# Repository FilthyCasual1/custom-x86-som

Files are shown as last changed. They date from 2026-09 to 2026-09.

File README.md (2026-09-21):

# Custom x86 SOM — placement handoff

Open `hardware/x86-som-preliminary.kicad_pro` in KiCad 10. The matching schematic has 18 sheets; the matching PCB contains 96 staged components and zero routed tracks. Project-local symbol and footprint libraries are included. Move components in the PCB editor to start exploring placement; no board outline has been chosen.

**This is an incomplete preliminary design, not fabrication-ready.** See `hardware/LIBRARY-STATUS.md` for the current verification matrix. The CPU socket and Q370 still use padless placement envelopes. Other packages include source-checked geometry and explicitly marked provisional choices. Electrical and assembly validation remains incomplete.

The full library is `hardware/SOM_Full.kicad_sym`; use `hardware/parts-catalog.json` for part numbers. CPU socket: Foxconn PE115127-4041-01H. DDR4 sockets: TE2309407-1. The full pin inventories have1151 CPU contacts,874 PCH balls and456 BMC balls.

## Files

- `hardware/x86-som-preliminary.kicad_sch`: source-based schematic draft.
- `hardware/x86-som-preliminary.kicad_pcb`: component staging board with nets assigned to available pads.
- `hardware/SOM.kicad_sym`, `hardware/SOM.pretty/`: portable project libraries.
- `hardware/footprint-status.json`: footprint provenance and provisional status.
- `hardware/placement-validation.json`: component count and schematic nodes without pads.
- `hardware/open-items.md`: next engineering checks.
- `output/pdf/x86-som-preliminary.pdf`: schematic preview.
- `docs/reference/`, `docs/manifest.json`: downloaded documents and source inventory.
- `research/conversation-source.json`: recovered original specification conversation.

KiCad successfully exported the schematic and reloaded the 96-component PCB. ERC reports 102 errors and 349 warnings; see `hardware/erc.rpt`. These remain unresolved, and no routing, signal-integrity, power-integrity, boot or fabrication validation has been claimed.

The source specification is ChatGPT conversation “Compact SOM Motherboard Design”, ID `6ab03890-806c-83ea-97a4-768561390f3c`. Prior assistant claims are research leads. The earlier claimed downloadable engineering packs were not recovered. Actual donor schematics and manufacturer documents have been downloaded separately.

Generation scripts are development tools. **Do not rerun them after manual KiCad edits:** they overwrite schematic/PCB files and regenerate symbol UUIDs.

## Public repository contents

This public snapshot contains the KiCad files, libraries, generation scripts, engineering notes and previews from local commit `4b89cf6`. The original conversation archive and downloaded third-party reference documents/text extracts remain local; paths to those files describe the local research workspace. `docs/manifest.json` records the source inventory. Some generators require those local source files and will not run from this public checkout alone.

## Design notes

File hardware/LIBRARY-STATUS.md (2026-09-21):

# Library handoff

`SOM_Full.kicad_sym` contains 17 entries. `FH82Q370` has all 874 ball numbers from Intel Table11-1; `AST2500A2_GP` has all 456 populated balls from the ASPEED top-view maps, excluding 28 #N/A sites. `CoffeeLake_LGA1151` contains 1151 donor-extracted contacts. Complete pin inventories are separate from the partial circuit symbols so existing draft connections are preserved. All full inventory pins are passive: electrical types and multiplexed functions still need independent review. This is not a complete, validated motherboard library.

All selected symbols expose Manufacturer, MPN, Footprint and Status fields in the full library; schematic instances also have those fields. `parts-catalog.json` is the machine-readable catalog. TBD values are deliberate, not orderable parts.

| Item | Manufacturer part | Status |
|---|---|---|
| CPU socket | Foxconn PE115127-4041-01H | Manufacturer drawing downloaded. Solder-ball numbering and land geometry unresolved; padless placement reservation retained. CPU itself is separate. |
| DDR4 sockets | TE 2309407-1 | 4mm, standard orientation. Checked drawing5 sheet2; signal pads corrected to0.30x1.75mm. |
| EPS header | Molex39-28-1083 | Candidate for5566-08A footprint. Exact EPS keying and pad mapping unresolved; not purchase-approved. |
| Q370 | Intel FH82Q370 |874-pin inventory;23x24mm body confirmed. Pitch and recommended lands unresolved; padless. |
| BMC | ASPEED AST2500A2-GP |456pads,19x19mm,0.8pitch and depopulation checked against drawing/maps.0.35mm NSMD copper diameter is an engineering proposal, not a verified manufacturer recommendation. |
| VR controller | ISL95866HRZ-T | Renesas L52.6x6A pattern:0.4pitch,0.20x0.55 peripheral pads,4.7mm EP. Package-to-device association donor-derived. Complete controller datasheet fetch was denied403. |
| Host PHY | WGI219LM family | Corrected EP from4.4 to3mm;0.4pitch. Exact stepping unresolved. Peripheral pad extension and thermal vias require assembly review. |
| DDR termination | TPS51200DRCR | KiCad DRC10+EP pattern; exact TI package selected. |
|25MHz crystal | ABM8-25.000MHZ-D2Y-T | Correct4-pin mapping; case pins2/4 grounded; pad geometry corrected to manufacturer1.30x1.05 at±1.15/±0.875mm. Load-capacitance/startup validation pending. |
| RTC crystal | ABS07-32.768KHZ-7-T | Candidate7pF crystal. Generic3215 footprint remains unverified against recommended lands. |
| PHY inductor | LPS4018-472MRC | Exact4.7uH candidate. Stock footprint differs from manufacturer's shaped recommended lands; unresolved. Current/ripple not approved. |
| Input fuse |0451015.MRL | Candidate15A package only; stock1.96x3.15mm pads at±2.455 match published recommended dimensions. Protection coordination not approved. |
| Flash, resistors, capacitors | TBD | Package templates only; exact electrical selection unresolved. |

The PCB contains96components, of which U1/U2 remain padless. There are1639 netlist nodes without pads, predominantly these two placeholders. Do not mistake the incomplete ratsnest for a complete design. ERC remains451messages:64open pins,38undriven supply inputs,349isolated labels. These represent unfinished circuitry and were not suppressed to produce a false clean report.

Do not rerun the generation scripts after manual KiCad edits: they overwrite files and regenerate UUIDs. The full inventory variants are available for future replacement of partial circuit symbols, not automatically substituted into this schematic.

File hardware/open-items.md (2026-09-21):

# Current status supersedes earlier checklist

See LIBRARY-STATUS.md. Only U1/U2 remain padless; missing pad nodes now1639. Earlier sizes and eight-placeholder list below are historical.

# Resume checklist

Work paused at user's requested symbol/footprint placement handoff.

1. Replace padless envelopes U1/U2/U3/U20/Y1/Y2/F1/L600 with exact orderable-part land patterns. CPU 78 x 78 mm envelope is an arbitrary socket/mechanism reservation, not its measured outline. Q370/AST2500/VR outlines are provisional too. Confirm all stock footprint pad mappings, EPS keying, SO-DIMM socket orientation and connector height. I219 exposed-pad size is a candidate, not independently validated.
2. Current symbols are incomplete for PCH and AST2500. CPU pin extraction has 1151 unique pins, but independent datasheet checking remains required. Donor H310 circuitry does not validate a Q370 design. AST2500 memory interface exists but its memory IC, complete supply pins and LAN circuit are absent.
3. Complete CPU VR power stages, inductors, compensation, rail sizing/sequencing, PCH/BMC regulators and full decoupling. The ISL95866 controller transcription is only a donor reference, not a complete VRM. TPS51200 REFIN uses a provisional 0.6 V divider.
4. Check DDR4 2DPC topology, SO-DIMM pin mapping, termination, SPD, VPP/VTT and length/impedance rules. No reference-board DQ swaps were assumed valid for this layout.
5. Complete host PHY support and BMC PHY/magnetics, RTC/clock/strap/reset circuits, carrier connector selection and allocation, firmware/BIOS/BMC bring-up plan. No carrier connector footprint is yet chosen or placed.
6. Resolve 451 ERC messages (102 errors / 349 warnings), including open pins, incomplete supplies and isolated nets. Board has 1780 netlist nodes without corresponding pads, predominantly major-chip placeholders. Do not interpret its incomplete ratsnest as complete connectivity.
7. Establish final cooler/socket datum and outline, stackup, routing rules and mounting. Do not manufacture the staging layout.

## Preserved mechanical inputs

User owns Dell 9020 USFF cooler; supplied part references 0VXD9P / 04X9H2 / 0FGW90 and https://www.ebay.com/itm/163252658404. User measured approximately 6 mm underside clearance at the far edge and 7+ mm under the fan. These are user-provided clearances, not verified full cooler geometry. Cooler geometry is only needed for board outline at this stage. No cooler keepout or board outline is frozen.

## Electrical allocation under consideration

Coffee Lake-S LGA1151 + Q370, four DDR4 SO-DIMMs, CPU 2 x PCIe x8, AST2500, one host I219-LM GbE plus dedicated BMC Ethernet, EPS12V. Proposed PCH lane allocation reserves lane 5 for integrated GbE, lane 6 for AST2500, lanes 13–24 as three x4 uplinks, and lanes 1–4/7–12 as ten x1 links. This remains subject to exact Q370 port grouping, HSIO and firmware checks.

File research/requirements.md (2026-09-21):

# Recovered requirements

Source turn IDs refer to conversation-source.json. Later user decisions supersede earlier alternatives.

| Requirement | Evidence / status |
|---|---|
| Custom-built compact SOM, not a purchased module | User e489a088-b775-43a3-9347-7546c615806f |
| LGA1151 socket | User ffe6aea0-88a6-45e8-87d1-2a5e93b71265 |
| Four SO-DIMM sockets; two direct x8 CPU PCIe links; extensive x1 expansion | Initial user f3331d3b-775d-45c0-b359-b6b09c3ab676 |
| Coffee Lake-S / Q370 platform | Working architecture from prior discussion; exact CPU SKU/support list remains open |
| ASPEED BMC | User 21da610f-d5e8-4298-b970-36f947f638f8; AST2500 was the proposed implementation |
| Native x1 links plus carrier switches | Accepted by user e3cca0a1-25ed-42ec-9e25-9c0096a0db84; numerical allocation needs correction |
| Single integrated host GbE | User 34e104bf-5dbd-4353-96c1-0a2119030bda supersedes dual-host-GbE request |
| Dedicated BMC management Ethernet | Working architecture; dual management Ethernet was an assistant misunderstanding, not a retained requirement |
| Dell OptiPlex 9020 USFF blower cooler; board length follows cooler | User 5504d366-3890-4078-8114-ad4ef38d9f11 and 4c18245f-9b8e-4f8e-9550-e49036dbaa59 |
| Cooler removal for RAM service acceptable | User 1222fbf4-fb03-4248-ab1a-631aa3162e16 |
| Prioritize VRM beneath cooler/blower; fit RAM where possible | User 8b330e31-4ca0-419f-be5c-208c1b9776f9 |
| Separate generic VRM heatsink acceptable | User f838818f-8efe-44ce-a342-ce01d8f6e62e |
| 8-pin EPS12V power connector | User 7c87185e-401d-4113-9492-df72ce8600a6 |
| Actual usable datasheets/downloads; mirrors acceptable; avoid payment-credit download sites | Multiple user turns on source page 2 and 7e52c8d3-5bae-4577-8053-9b922b5472e5 |
| KiCad | Current user instruction |

## Decisions still open

Exact CPU SKU and sustained/transient limits; cooler part number/dimensions; connector family and pinout; SATA/USB/display counts; standby source; full power sequencing; firmware implementation and provisioning; CPU VR controller/stages; BMC RAM and flash sizing; TPM and Super I/O need; production quantity/cost target; fabricator and stackup.

The previous assistant's suggestions of 95 W electrical capability, 65 W cooling, 12–16 layers, heavy copper, specific heatsink dimensions and 12 V-derived standby are not verified requirements or validated limits.

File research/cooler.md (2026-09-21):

# Dell 9020 USFF cooler

User owns the physical cooler and explicitly authorized internet research and estimates for initial design. Proceed with provisional mechanical planning; dimensions are not a reason to stop the research.

User-specified cooler reference: **0VXD9P / 04X9H2 / 0FGW90**, supplied with [eBay listing 163252658404](https://www.ebay.com/itm/163252658404). The listing was opened and confirms those three identifiers in its title for the Dell 9020 USFF CPU fan/heatsink. Use this assembly as the mechanical research target. The listing does not establish that all three numbers denote interchangeable complete assemblies or provide a dimensioned mechanical drawing. The separate OEM assembly listing below identifies 4X9H2 as the assembly number; exact fan/subassembly mapping remains unverified.

Sources found:

- [Dell official USFF removal procedure](https://www.dell.com/support/manuals/en-us/optiplex-9020-desktop/opt9020usffom-v2/removing-the-heat-sink-assembly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): primary reference for assembly context and retention. Inspect illustrations before deriving geometry.
- [Parts-People OEM assembly listing](https://www.parts-people.com/index.php?action=item&id=25822): seller identifies the USFF assembly as 4X9H2; corroboration lead, not a dimensioned drawing.

No dimensions have been verified or estimated yet. Next: inspect official illustrations and available orthogonal photographs; build a parameterized envelope and label each inferred dimension with its source and uncertainty. Keep socket datum, fastener positions, blower intake clearance, SO-DIMM service envelope and VRM heatsink envelope separately adjustable. Do not release fabrication holes or claim cooling performance from photo estimates.

Latest user measurements: ~6 mm clearance at far edge, 7+ mm directly under fan. Cooler geometry is deferred to board outline; no outline fixed at placement handoff.

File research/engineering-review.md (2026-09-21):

# Initial engineering review

## Confirmed source access

Opened these complete PDFs through the web tool during intake; not yet downloaded locally:

- [Intel CPU 337344-009](https://cdrdv2-public.intel.com/337344/337344_8th-gen-core-family-datasheet-vol-1_Rev009.pdf): 155 PDF pages.
- [Intel PCH 337347-009](https://cdrdv2-public.intel.com/337347/337347_CNL_PCH_EDS_H_009.pdf): 301 PDF pages. Printed pages differ from PDF indices.

## HSIO conflict requiring correction

Intel 337347 Table 1-4 and Section 3 show shared PCIe/GbE/SATA resources. Integrated GbE consumes a PCIe-capable HSIO lane. Thus the inherited allocation of AST2500 x1 + eleven native x1 + three x4 uplinks (24 PCIe lanes) cannot also retain integrated GbE. The 15-root-port limit with GbE is a separate constraint; meeting it does not fix lane multiplexing.

An arithmetic starting point is ten native x1 + AST2500 x1 + three x4 uplinks = 23 PCIe lanes, reserving one HSIO lane for GbE. This is not a validated lane map. SATA reservations may reduce expansion further. Verify numbered lanes, controller groupings, straps and clock ownership before accepting it. If 24 carrier x1 endpoints remain desired, switches would need fourteen downstream x1 ports total with ten native links.

## Candidate parts inherited from discussion

These are leads only: no stock, price, exact order code or electrical compatibility has been verified in this intake.

| Block | Candidate | Required next evidence |
|---|---|---|
| CPU socket | TE 2287402-1 / Foxconn 3H993921-4M41-02H | Exact package, ball map, ILM, mounting and availability |
| SO-DIMM sockets | TE 2309407-5 | Stack height, insertion/retention envelope, drawing and footprint |
| BMC | AST2500 | Full pinout, power/reset sequence, DDR topology and firmware support |
| Host PHY | I219-LM | Correct generation/order code for Q370, supply and shared HSIO mapping |
| Management PHY | DP83867IS | AST2500 RGMII timing, supply compatibility, exact package |
| CPU VR | ISL95856 / ISL95866C / ISL69138 | Full documentation, SVID support, phases, stage interface, transient budget |
| Power stage | ISL99227 family | Controller compatibility; do not combine merely because both were suggested |
| Memory power | TPS51116 / TPS51200 | Host and BMC current budgets, VPP and sequencing |
| Carrier switches | PEX8713 | Full databook, straps, downstream widths, procurement and firmware |
| Clock buffers | 9DB836 / 9DBL0641 | Clock tree, loading, jitter budget, termination and enable control |
| Flash | W25Q256JV | Firmware capacity, bus voltage, boot addressing and recovery ownership |
| TPM | SLB9670 | Whether required; package and SPI electrical compatibility |

Earlier messages proposed PEX8714 for x1 fanout and later retracted it. Keep it excluded pending independent width-support verification. Earlier BMC RAM examples were also retracted over lifecycle concerns; no RAM part is frozen.

## Blocking inputs for real layout

- Exact cooler geometry and board/carrier datums are unavailable locally. Do not invent board dimensions or assume the cooler proves a particular power rating.
- CPU/PCH design guides, complete ball maps, memory routing limits and full selected VR documentation need acquisition and revision checks.
- Firmware feasibility must cover memory initialization, Intel CSME configuration, GPIO/HSIO straps, CPU support, flash programming and BMC recovery.
- Carrier pin budget must include grounds, clocks, reset/clock-request sidebands, management and power, not just differential data contacts.
- Full schematic connectivity and a supported fabrication stackup must precede production routing.

Next work: retrieve electrical documents, validate the numbered HSIO map, and compare exact parts and mechanical envelopes. User was asked for any existing downloaded document/design folder and cooler part number.

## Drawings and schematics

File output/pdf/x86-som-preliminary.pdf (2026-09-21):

1 | 2 | 3 | 4 | 5 | 6 | 7 | 8 | 9 | 10 | 11

AB

C

D

E

## FGH

AB

C

D

E

## FGH Date:

Size: A2 | Rev:
KiCad E.D.A. 10.0.6 | Id: 1/18

# Title:

## File: x86-som-preliminary.kicad_sch

## Sheet: /

CPU display and audio interface inventory

File: 07_cpu_display.kicad_sch

Q370 PCIe lane inventory / draft allocation

File: 09_pch_expansion.kicad_sch CPU remaining debug / reserved contacts

File: 08_cpu_reserved_7.kicad_sch

EPS12V input and unresolved regulator interfaces

File: 14_input_power.kicad_sch

AST2500 host links, boot flash and reset File: 13_bmc_host.kicad_sch Q370 power-domain interface inventory

# File: 12_pch_power.kicad_sch Q370 USB2 and PCIe clocks

File: 11_pch_usb_clocks.kicad_sch Q370 boot flash, LPC and reset interfaces

File: 10_pch_boot.kicad_sch

CPU VR controller / source-based starting circuit File: 15_vrm_controller.kicad_sch

CPU rails and power-pin inventory

File: 06_cpu_power.kicad_sch DDR4 supply interfaces, termination and socket power File: 05_memory_power.kicad_sch DDR4 channel B / two SO-DIMMs

# File: 04_ddr_b.kicad_sch DDR4 channel A / two SO-DIMMs

# File: 03_ddr_a.kicad_sch CPU PEG / two x8 carrier links

# File: 02_cpu_peg.kicad_sch CPU / Q370 DMI, clocks and sideband

File: 01_cpu_platform.kicad_sch | Host GbE PHY / I219 reference circuit File: 16_host_lan.kicad_sch AST2500 local DDR4 / pin-level interface

File: 17_bmc_ddr.kicad_sch

Known omissions: CPU VRM / sequencer / BMC DDR+power+LAN / host PHY / full PDN / connector pinout / remaining PCH GPIO.

# CUSTOM x86 SOM / preliminary schematic v0.1

SOURCE-BASED ELECTRICAL DRAFT - incomplete circuits are listed on each sheet Coffee Lake-S + Q370 + four DDR4 SO-DIMMs + AST2500

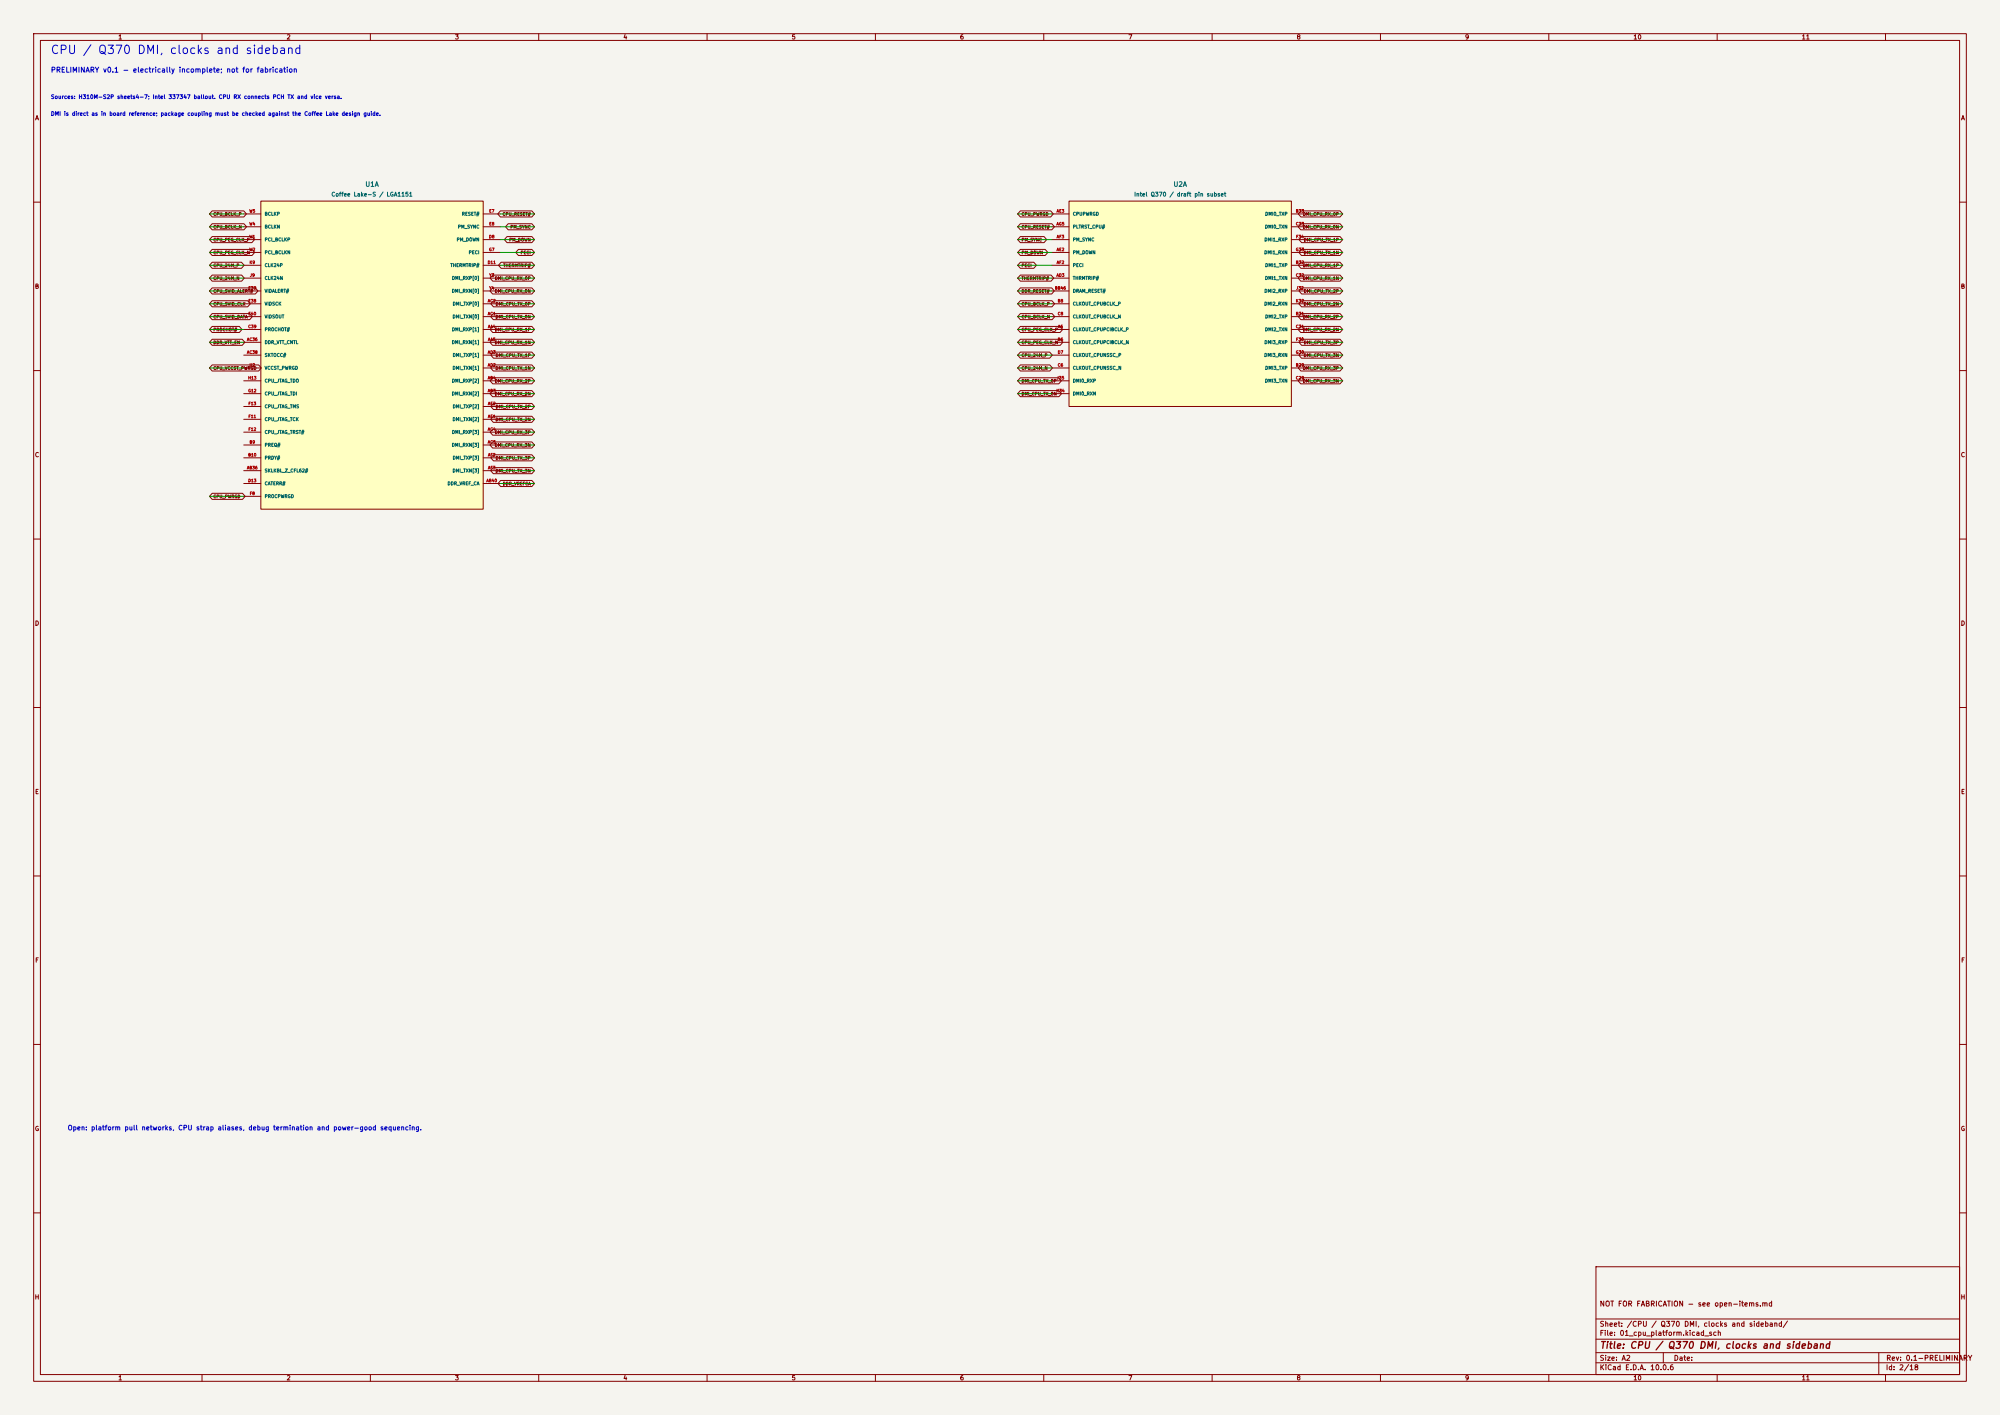
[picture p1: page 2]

PM_SYNC CPU / Q370 DMI, clocks and sideband

PRELIMINARY v0.1 - electrically incomplete; not for fabrication

Sources: H310M-S2P sheets4-7; Intel 337347 ballout. CPU RX connects PCH TX and vice versa. DMI is direct as in board reference; package coupling must be checked against the Coffee Lake design guide.

Open: platform pull networks, CPU strap aliases, debug termination and power-good sequencing.

NOT FOR FABRICATION - see open-items.md

Sheet: /CPU / Q370 DMI, clocks and sideband/
File: 01_cpu_platform.kicad_sch
Title: CPU / Q370 DMI, clocks and sideband

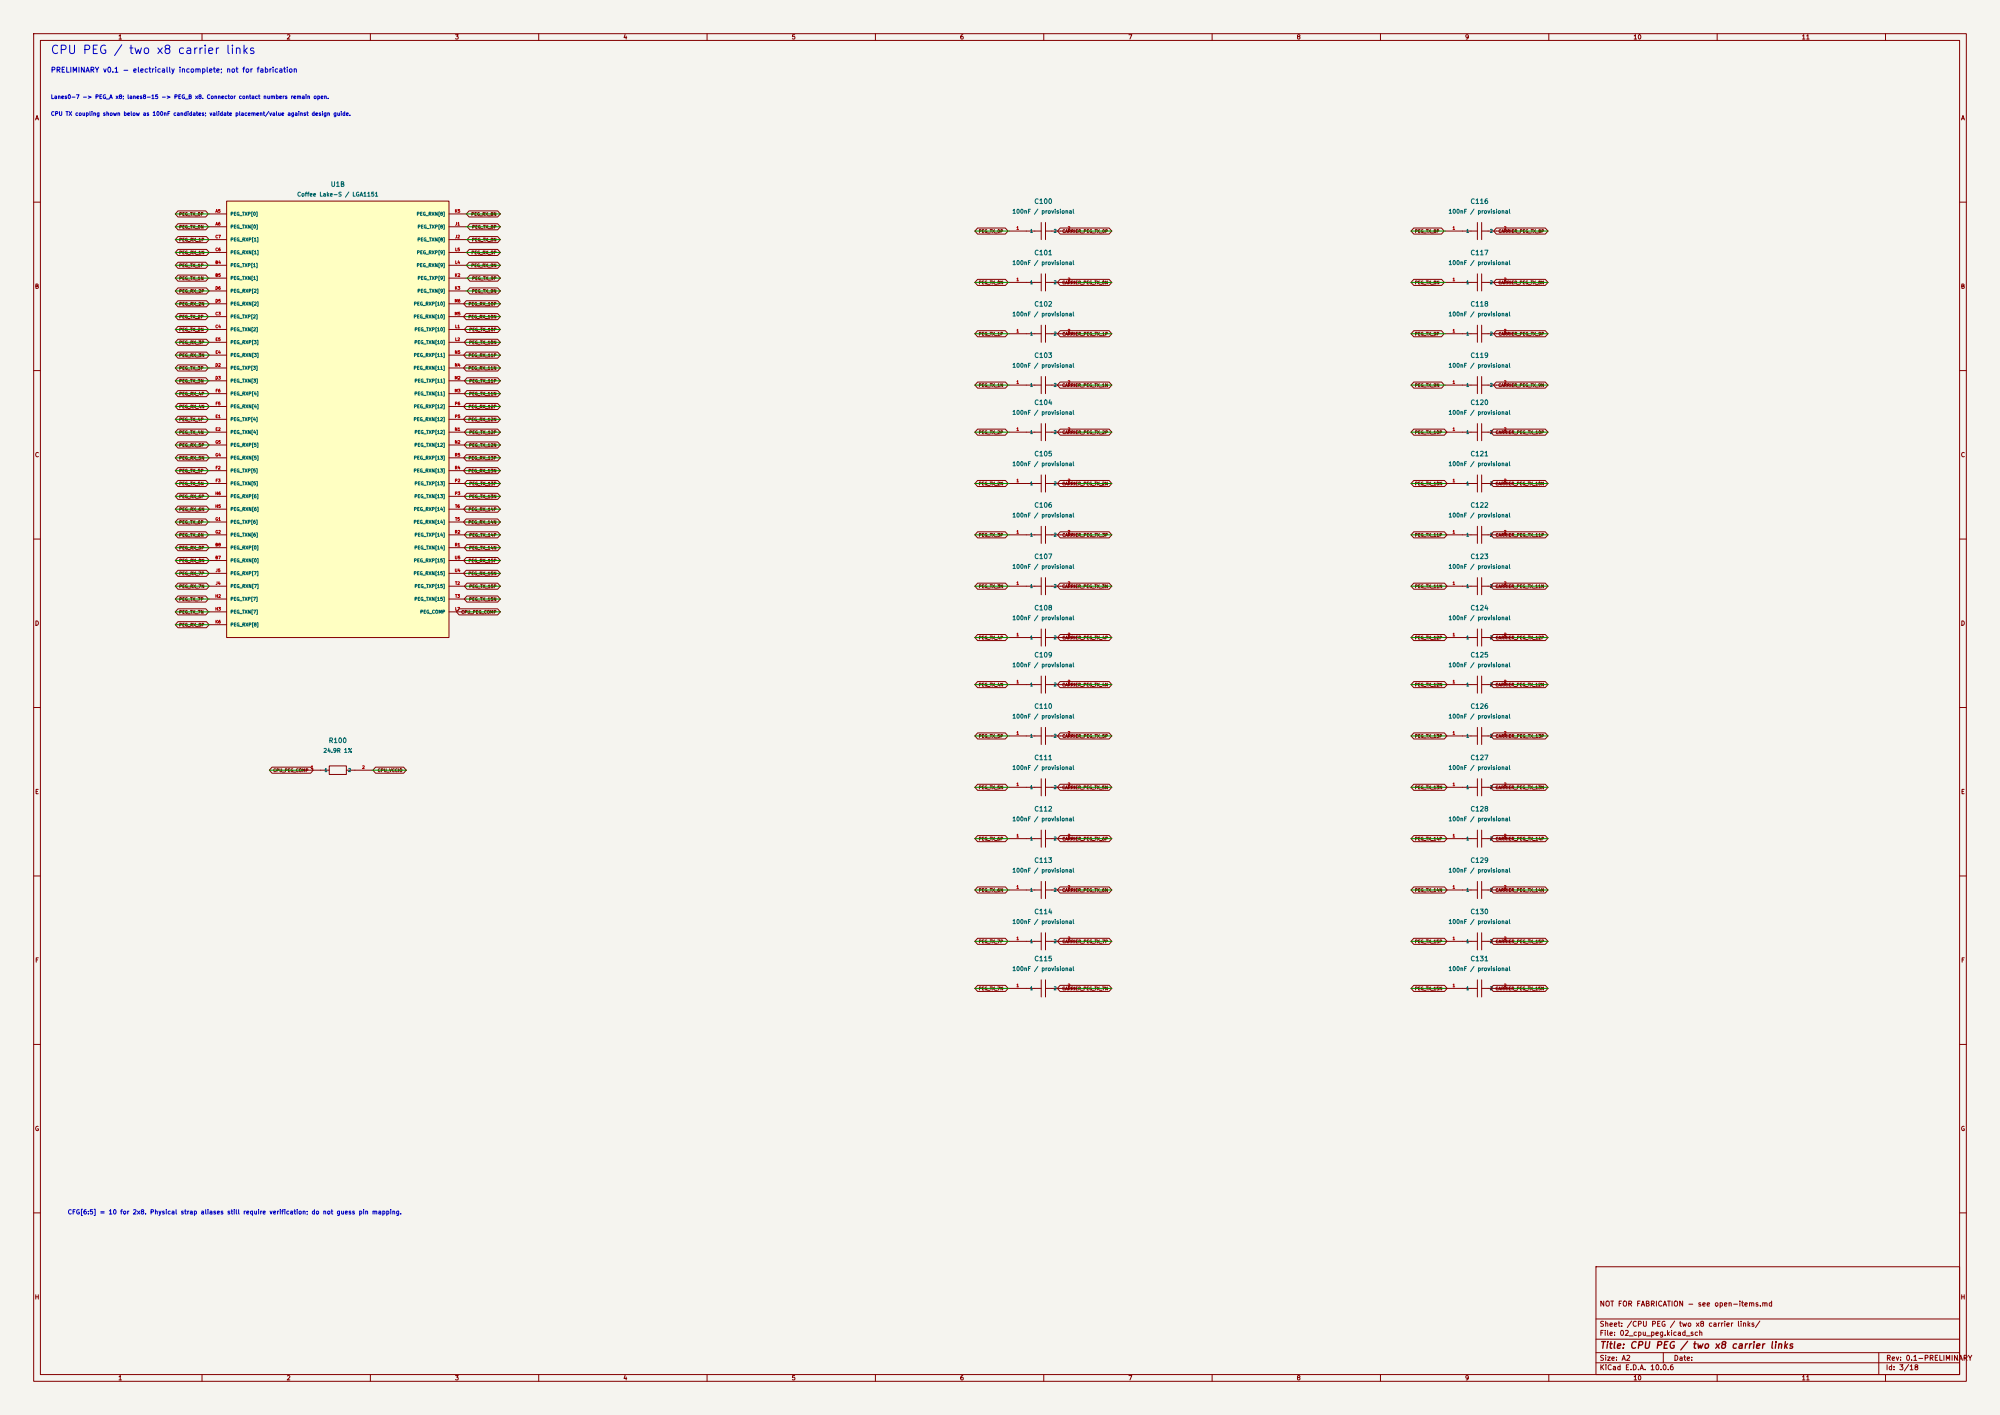
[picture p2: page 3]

CPU PEG / two x8 carrier links

Lanes0-7 -> PEG_A x8; lanes8-15 -> PEG_B x8. Connector contact numbers remain open. PRELIMINARY v0.1 - electrically incomplete; not for fabrication

CPU TX coupling shown below as 100nF candidates; validate placement/value against design guide.

CFG[6:5] = 10 for 2x8. Physical strap aliases still require verification; do not guess pin mapping.

Sheet: /CPU PEG / two x8 carrier links/
File: 02_cpu_peg.kicad_sch
Title: CPU PEG / two x8 carrier links

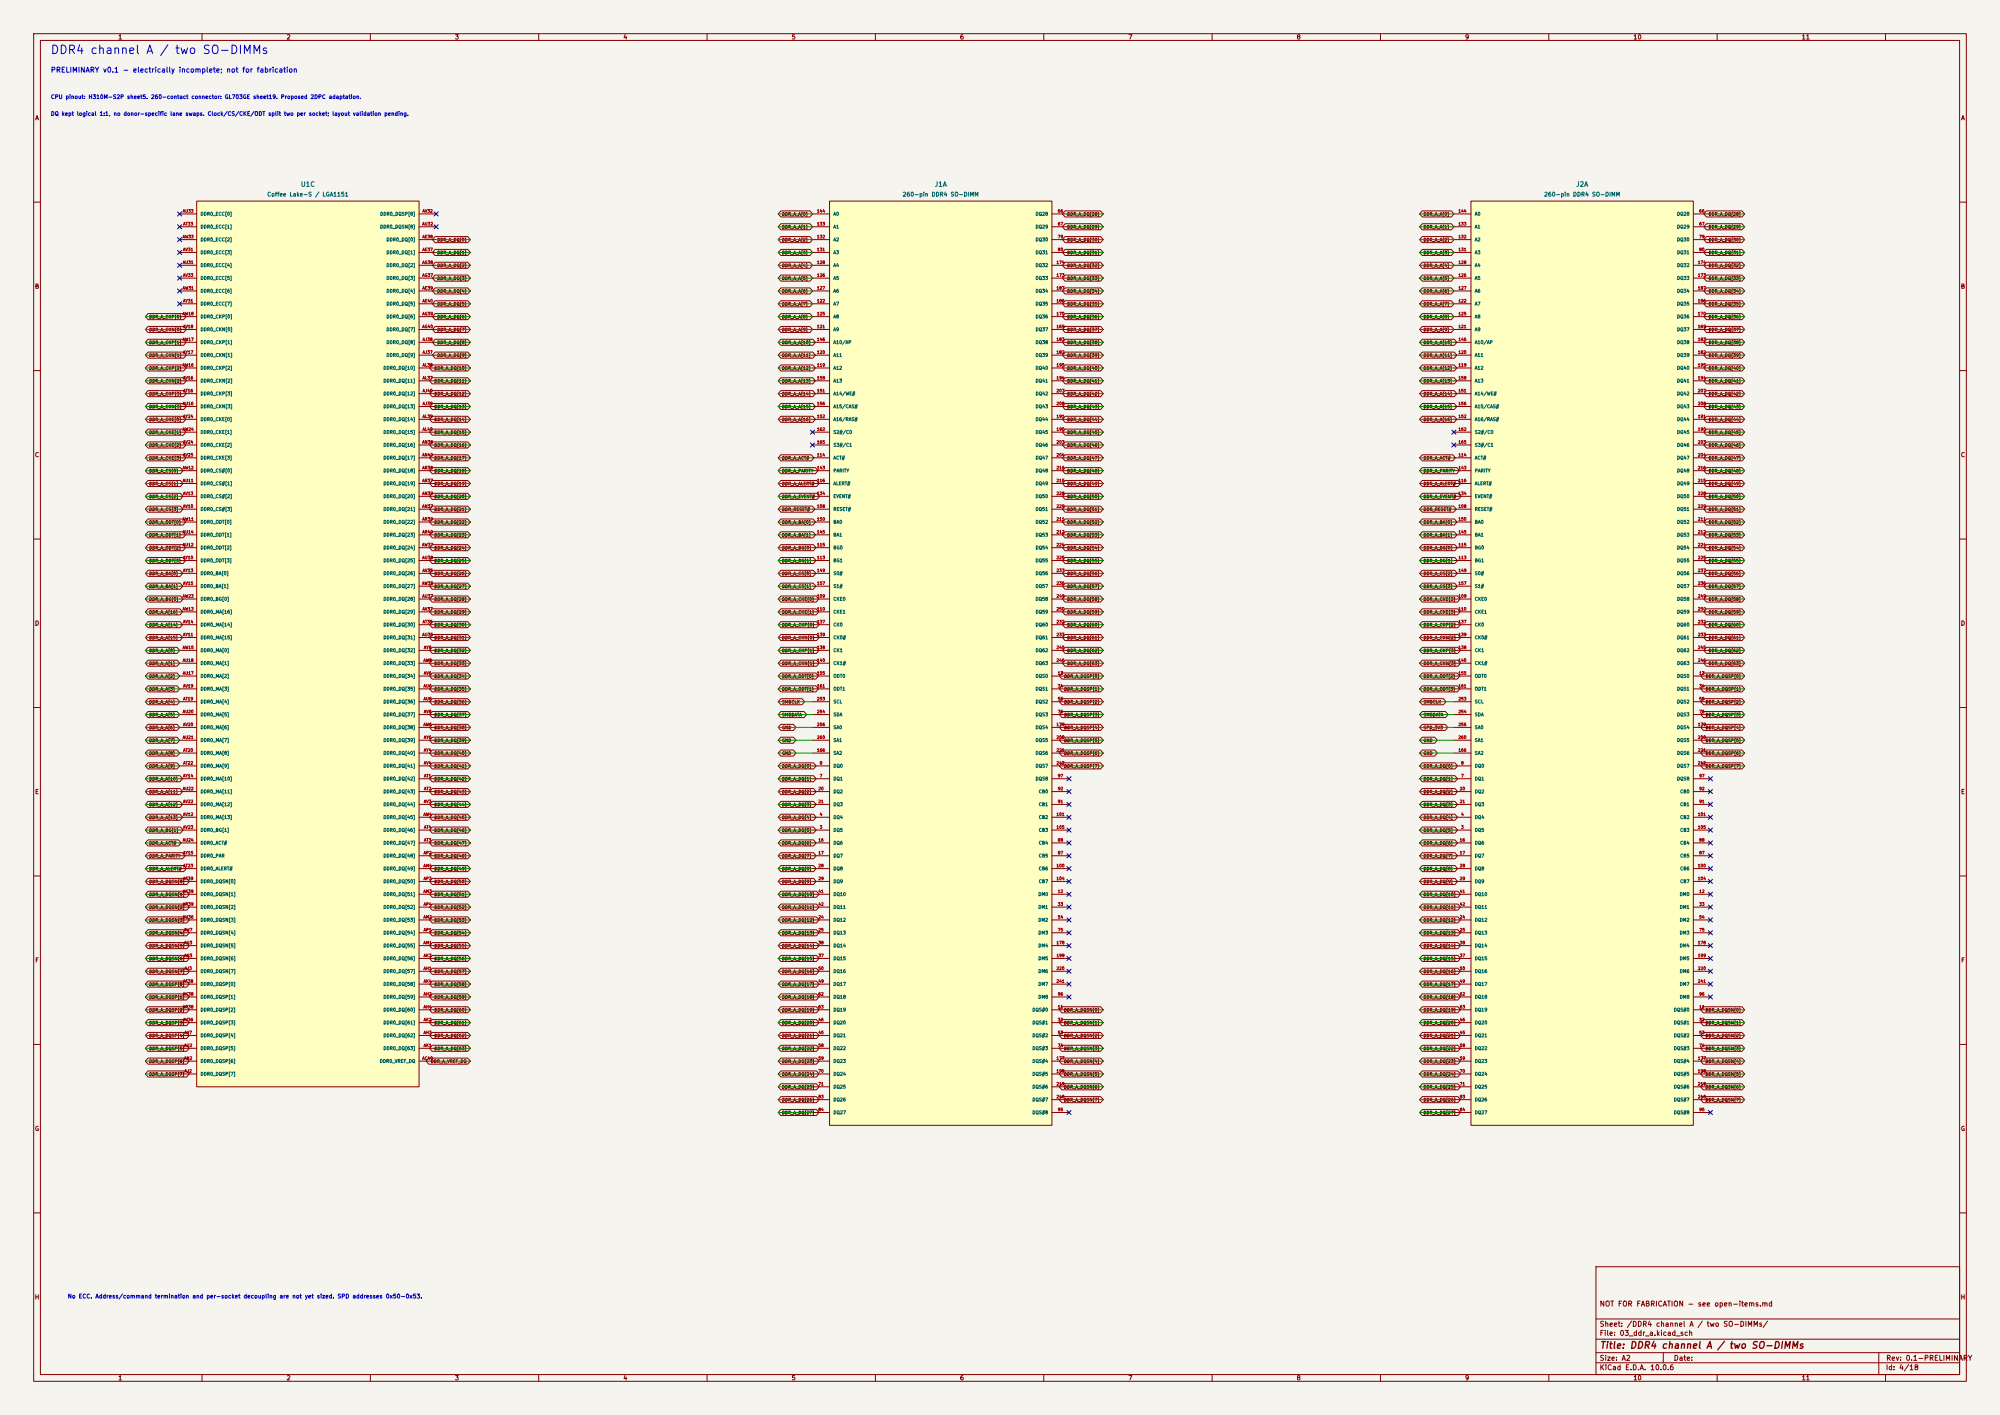
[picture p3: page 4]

DDR4 channel A / two SO-DIMMs

DQ kept logical 1:1, no donor-specific lane swaps. Clock/CS/CKE/ODT split two per socket; layout validation pending. CPU pinout: H310M-S2P sheet5. 260-contact connector: GL703GE sheet19. Proposed 2DPC adaptation.

No ECC. Address/command termination and per-socket decoupling are not yet sized. SPD addresses 0x50-0x53.

Sheet: /DDR4 channel A / two SO-DIMMs/
File: 03_ddr_a.kicad_sch
Title: DDR4 channel A / two SO-DIMMs

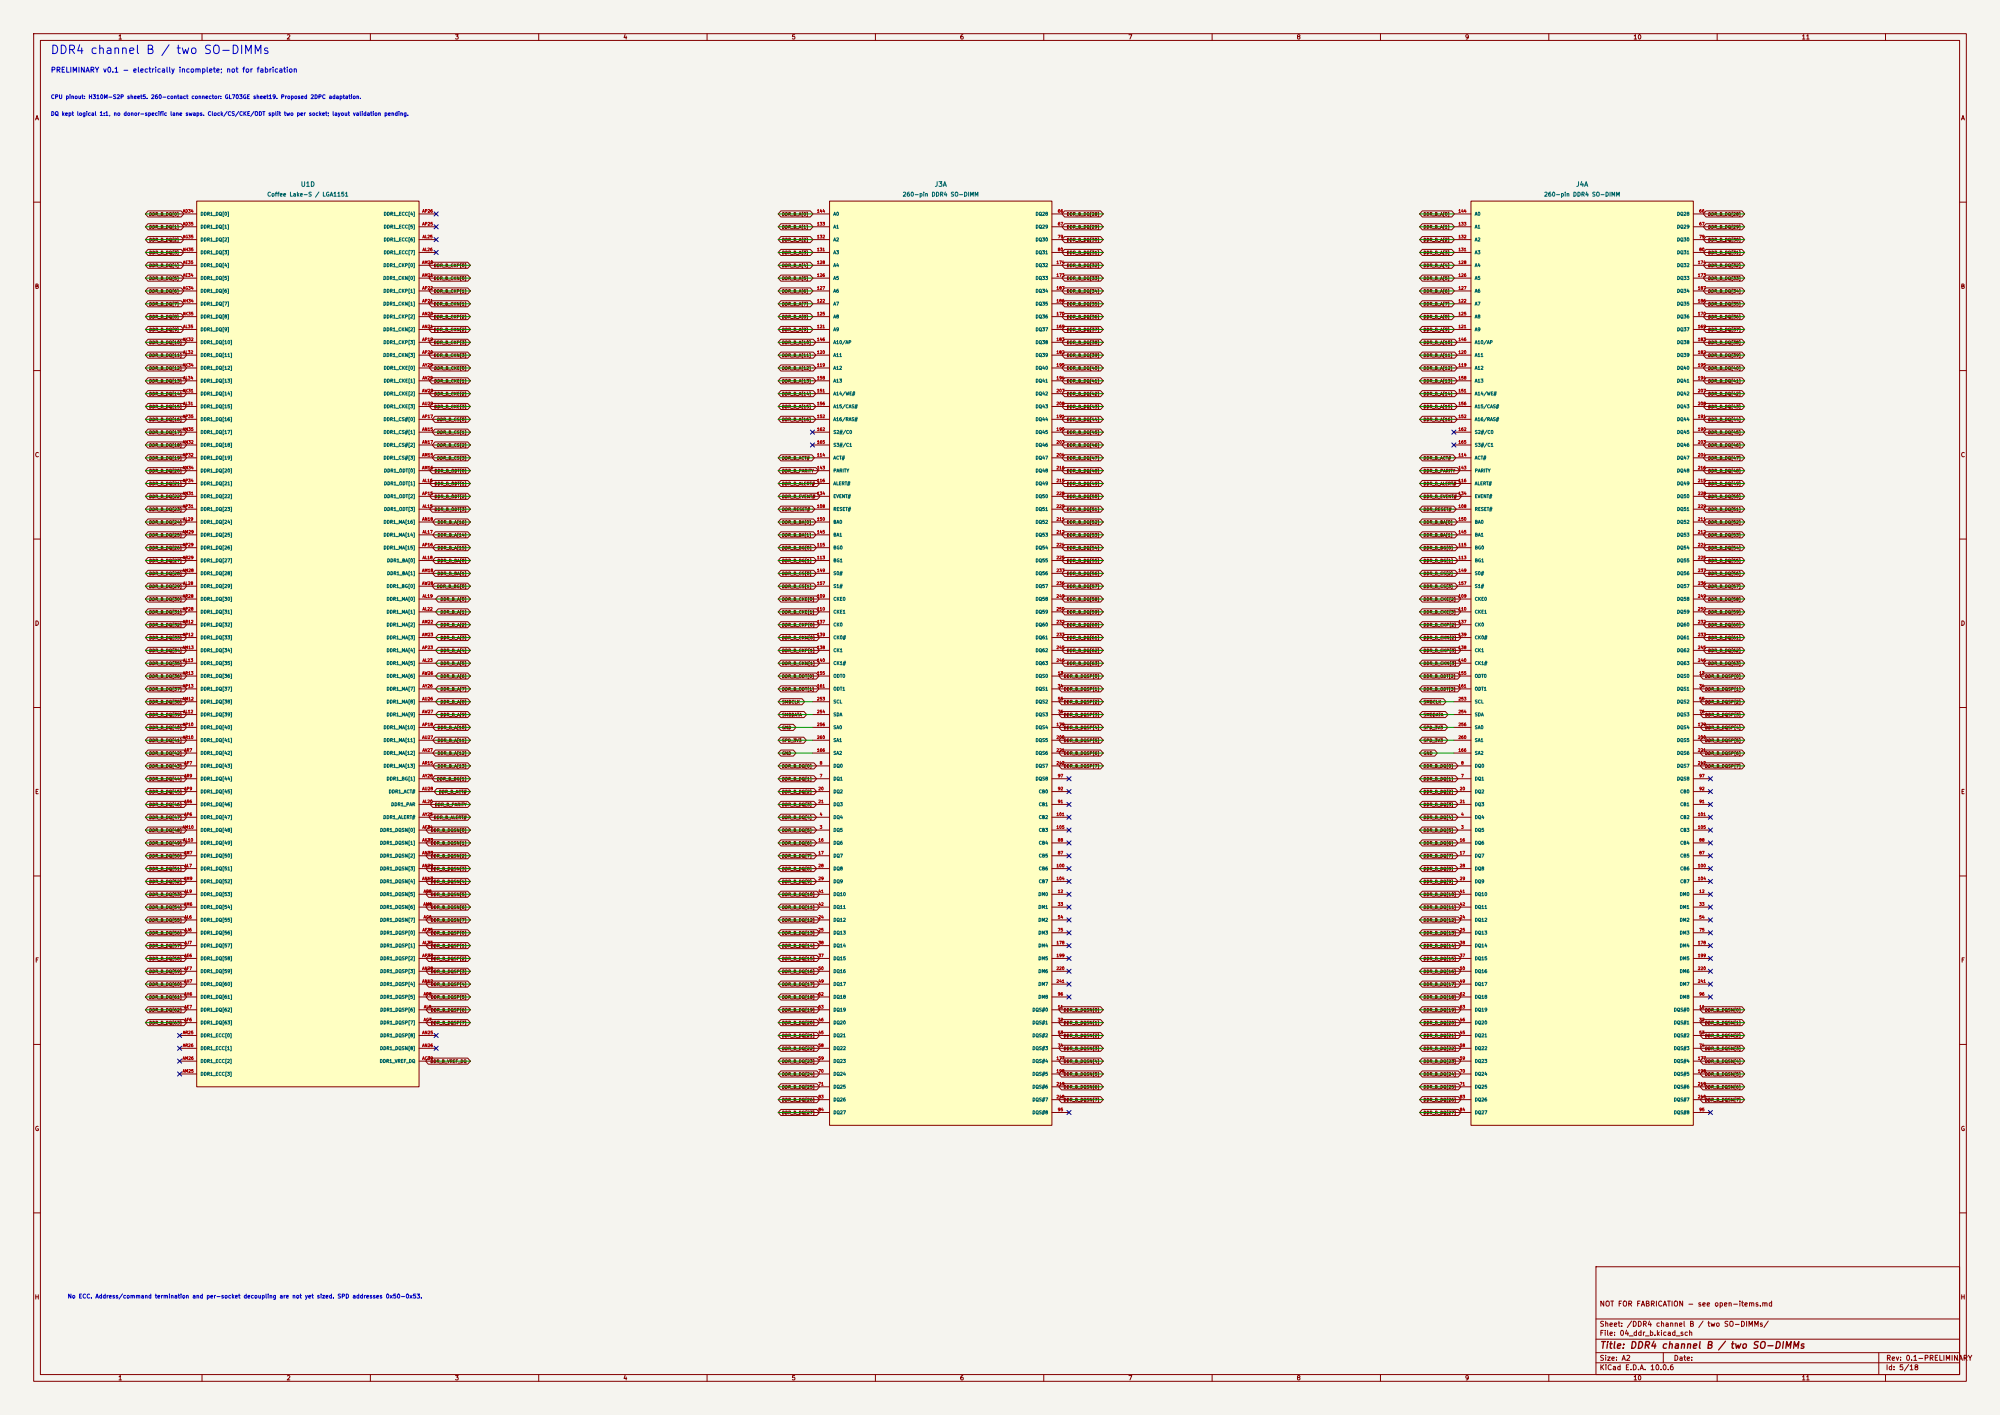
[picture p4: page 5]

DDR_B_DQ[8] DDR4 channel B / two SO-DIMMs

CPU pinout: H310M-S2P sheet5. 260-contact connector: GL703GE sheet19. Proposed 2DPC adaptation. DQ kept logical 1:1, no donor-specific lane swaps. Clock/CS/CKE/ODT split two per socket; layout validation pending.

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

Sheet: /DDR4 channel B / two SO-DIMMs/
File: 04_ddr_b.kicad_sch
Title: DDR4 channel B / two SO-DIMMs

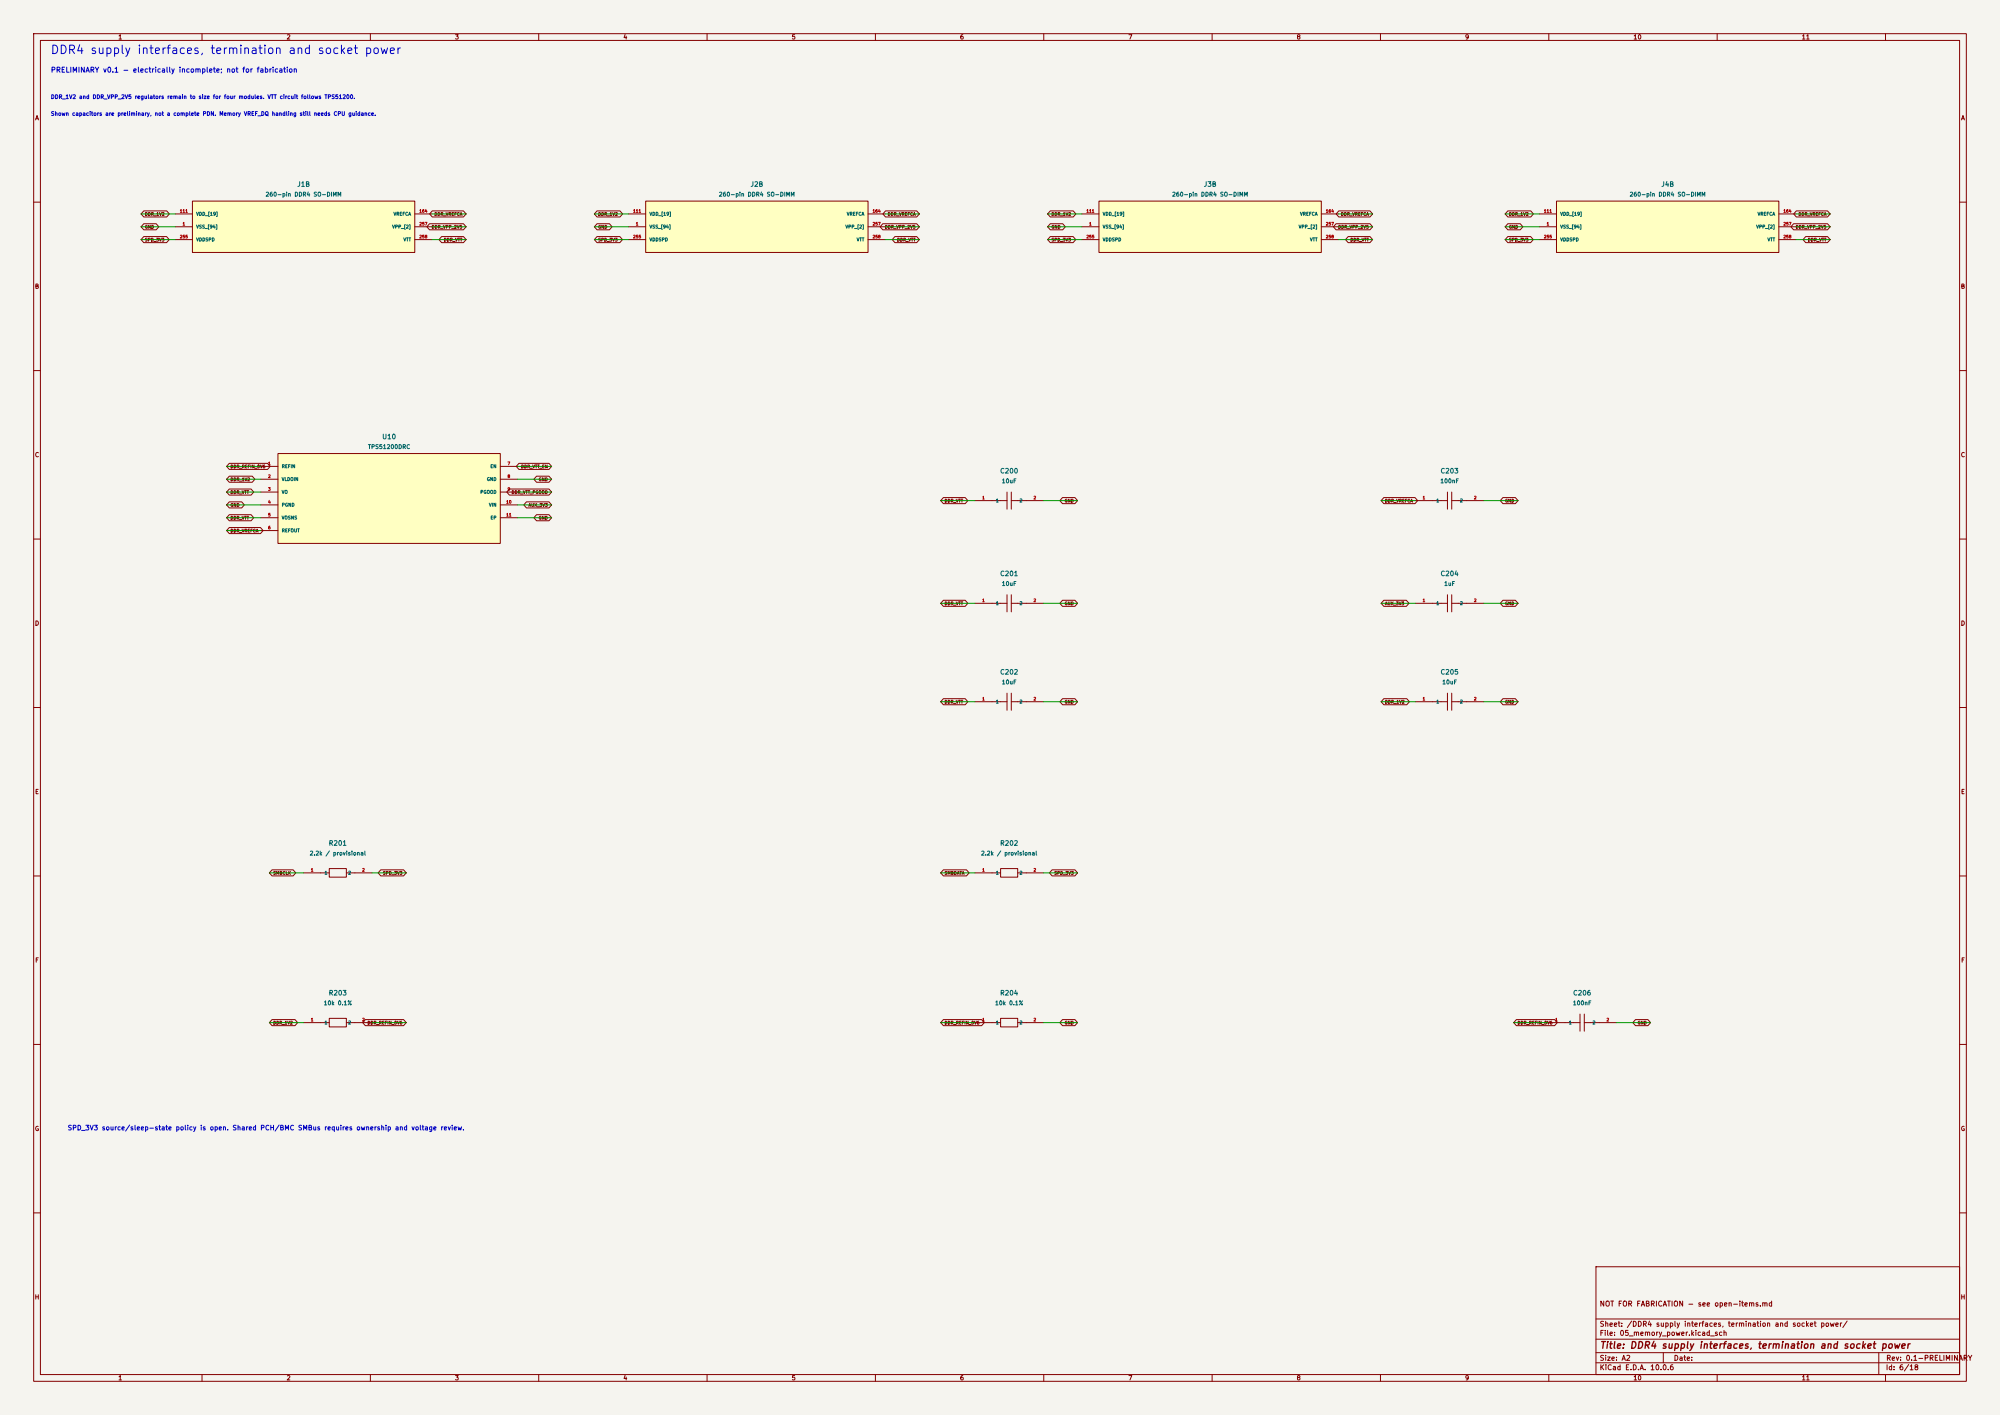
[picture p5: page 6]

Shown capacitors are preliminary, not a complete PDN. Memory VREF_DQ handling still needs CPU guidance. DDR_1V2 and DDR_VPP_2V5 regulators remain to size for four modules. VTT circuit follows TPS51200. PRELIMINARY v0.1 - electrically incomplete; not for fabrication

SPD_3V3 source/sleep-state policy is open. Shared PCH/BMC SMBus requires ownership and voltage review.

Sheet: /DDR4 supply interfaces, termination and socket power/
File: 05_memory_power.kicad_sch
Title: DDR4 supply interfaces, termination and socket power

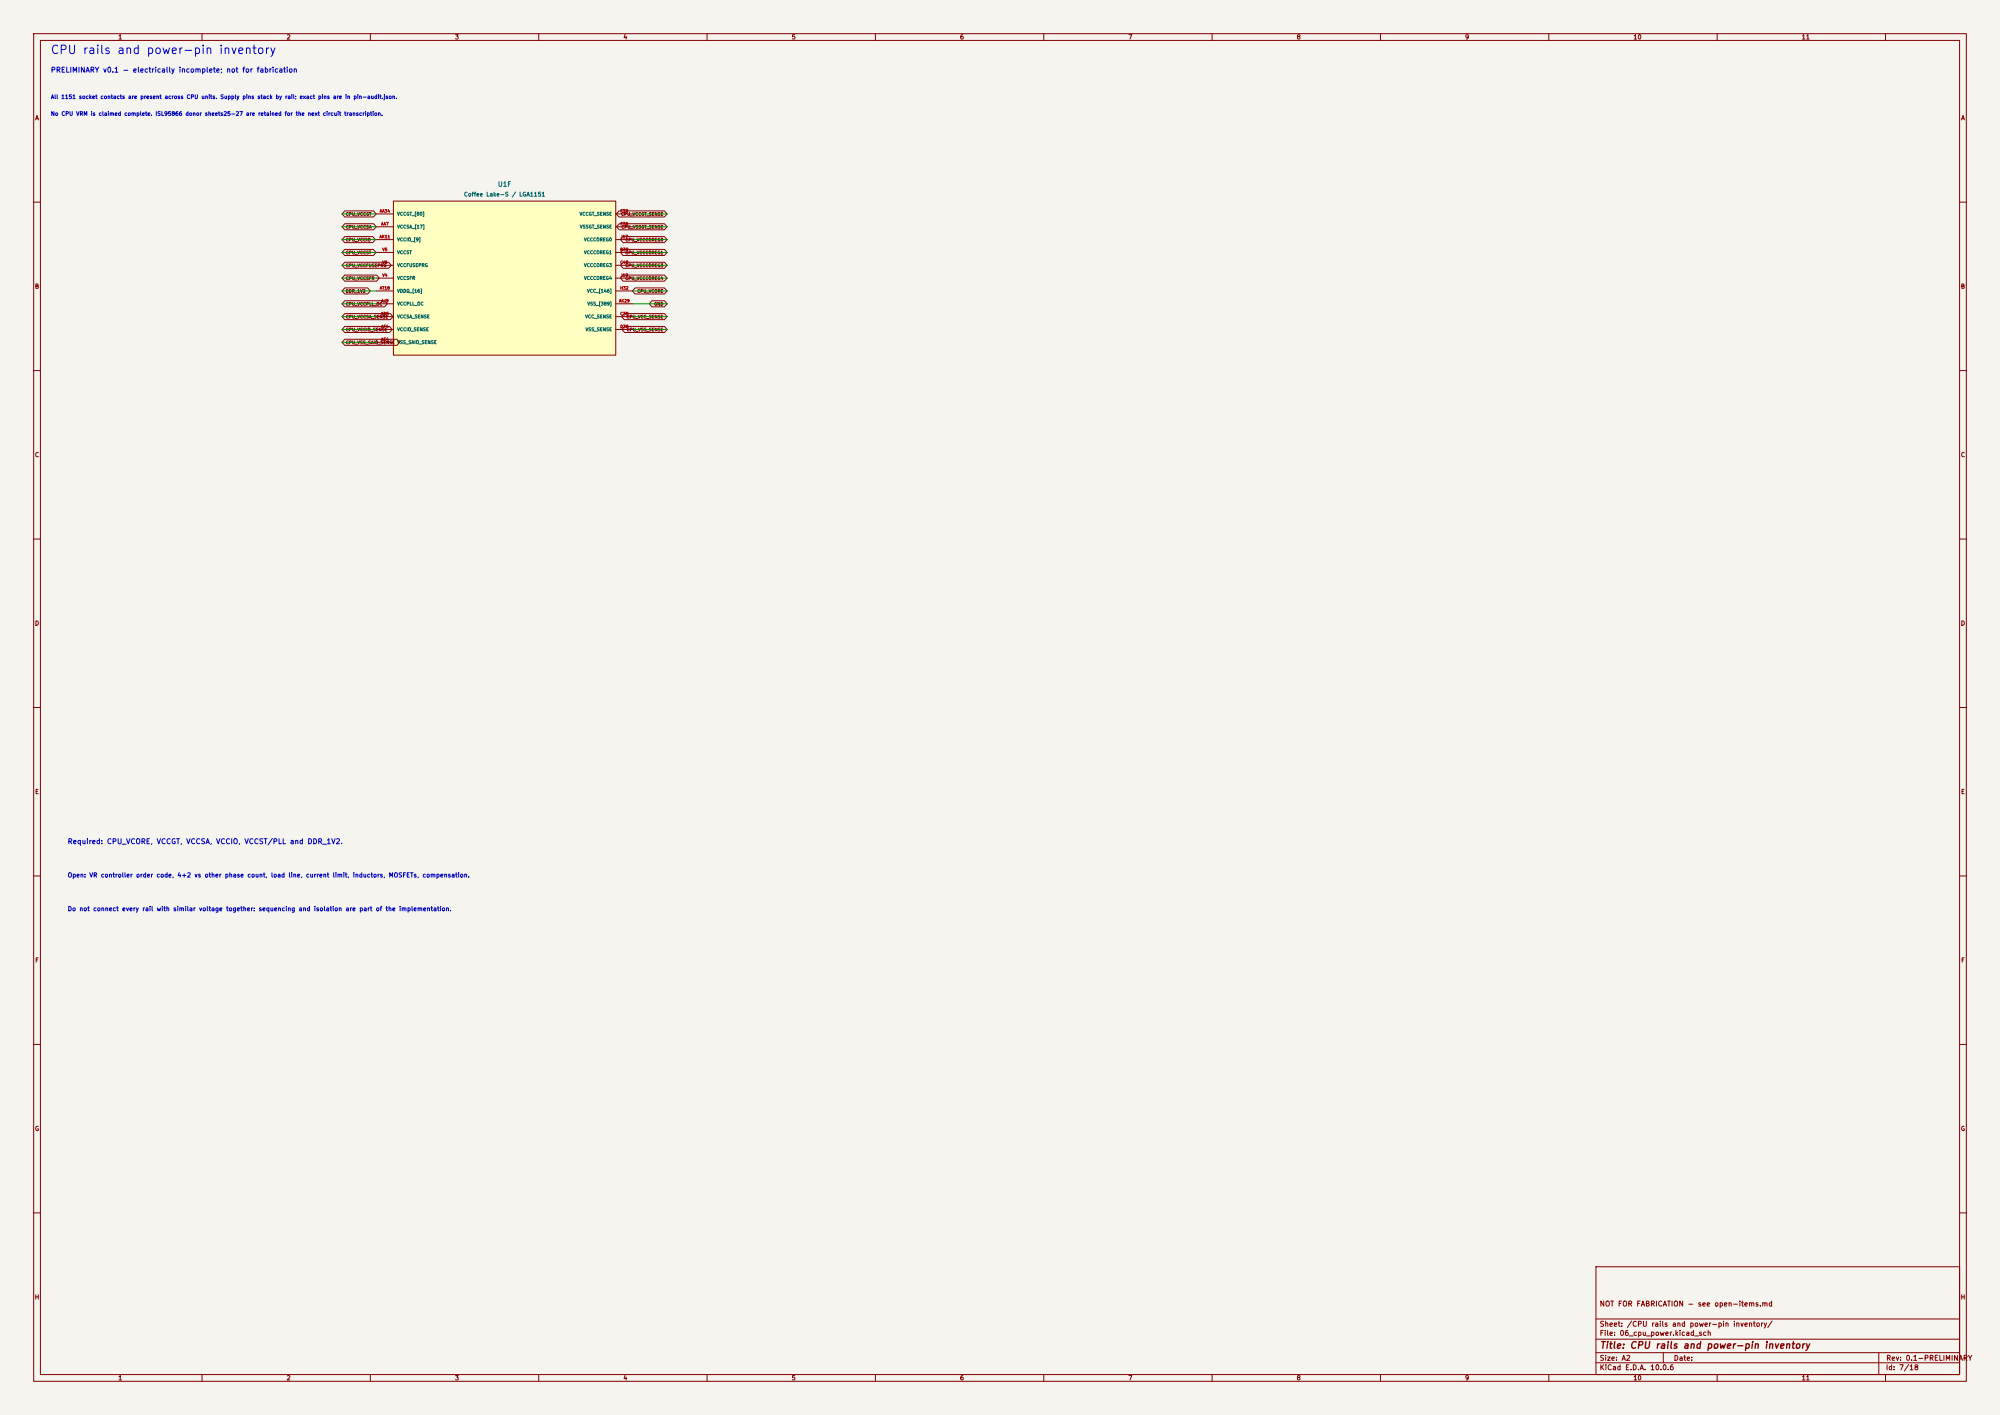
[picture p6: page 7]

CPU rails and power-pin inventory
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

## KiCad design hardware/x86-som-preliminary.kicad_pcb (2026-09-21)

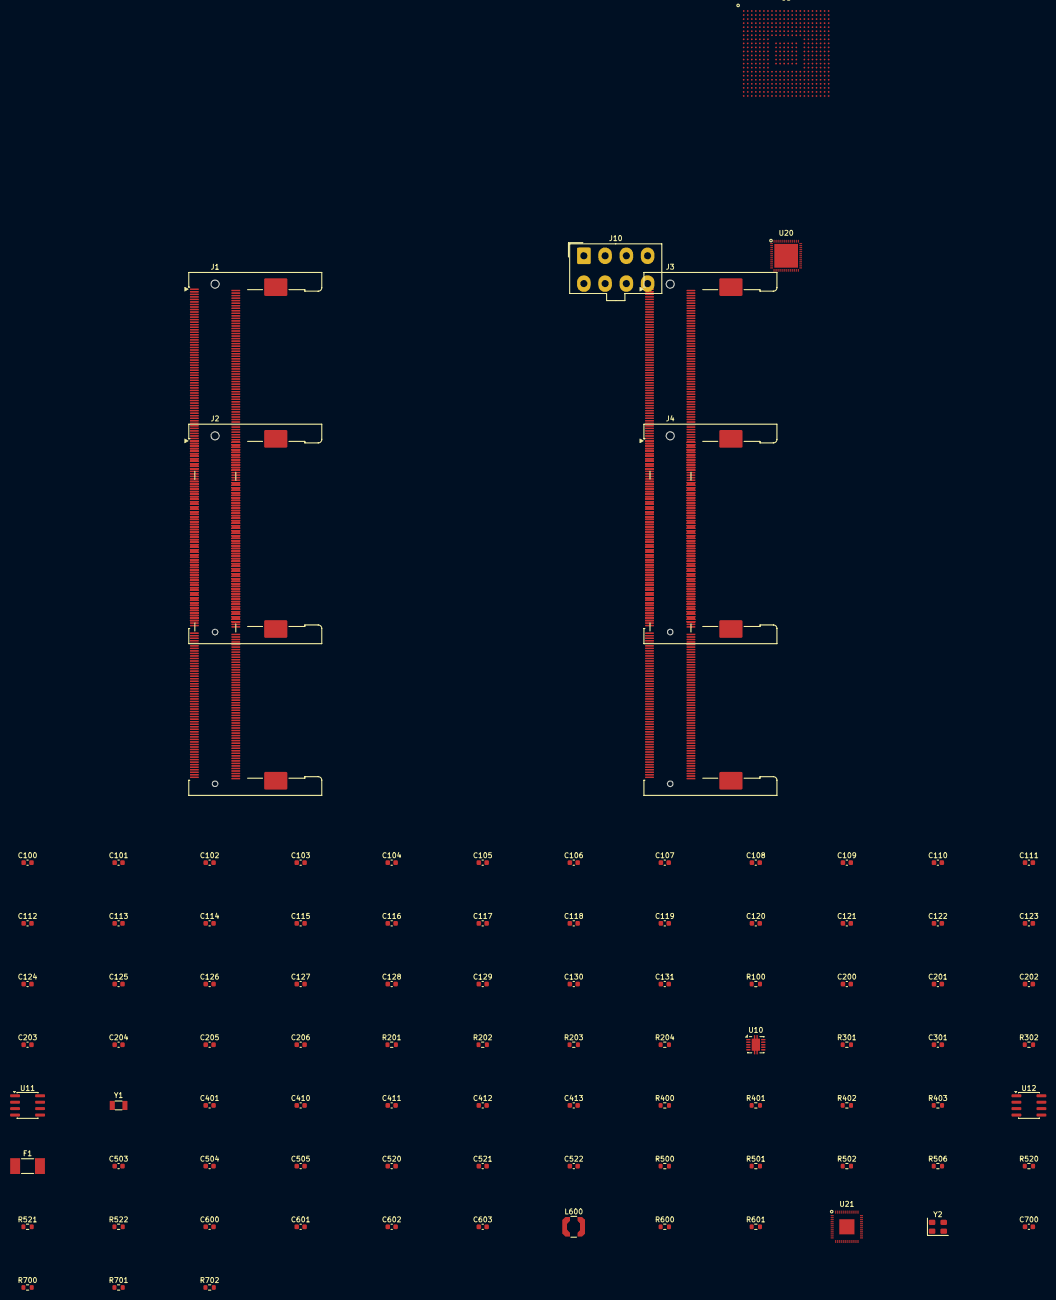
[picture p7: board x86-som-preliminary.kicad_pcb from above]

Board: 2 copper layers, 96 parts (0 on the bottom side), 267 nets, no tracks yet.

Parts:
C100, C101, C102, C103, C104, C105, C106, C107, C108, C109, C110, C111, C112, C113, C114, C115, C116, C117, C118, C119, C120, C121, C122, C123, C124, C125, C126, C127, C128, C129, C130, C131, C410, C411, C412, C413, C600, C601, C602, C603: 100nF / provisional; C_0603_1608Metric
C200, C201, C202, C205: 10uF; C_0603_1608Metric
C203, C206, C301, C401, C700: 100nF; C_0603_1608Metric
C204, C503, C504, C505: 1uF; C_0603_1608Metric
C520, C521, C522: 220nF / donor; C_0603_1608Metric
F1: Fuse / rating TBD; Fuse_Littelfuse-NANO2-451_453
J1, J2, J3, J4: 260-pin DDR4 SO-DIMM; SODIMM-260_DDR4_H4.0-5.2_OrientationStd_Socket
J10: EPS12V 8-pin; Molex_Mini-Fit_Jr_5566-08A_2x04_P4.20mm_Vertical
L600: 4.7uH / Intel; L_Coilcraft_LPS4018
R100, R301: 24.9R 1%; R_0603_1608Metric
R201, R202: 2.2k / provisional; R_0603_1608Metric
R203, R204: 10k 0.1%; R_0603_1608Metric
R302, R402, R403: 10k / provisional; R_0603_1608Metric
R400: 200R 1%; R_0603_1608Metric
R401: 10k; R_0603_1608Metric
R500, R501, R502: 2.2R; R_0603_1608Metric
R506: 2.87k 1% / donor; R_0603_1608Metric
R520, R521, R522: 2.2R / donor; R_0603_1608Metric
R600: 3.01k 1%; R_0603_1608Metric
R601: 1k; R_0603_1608Metric
R700: 240R 1%; R_0603_1608Metric
R701, R702: 10k 0.1% / provisional; R_0603_1608Metric
U1: Coffee Lake-S / LGA1151; CoffeeLake_LGA1151_PLACEMENT_ONLY
U2: Intel Q370 / draft pin subset; Q370_draft_PLACEMENT_ONLY
U3: AST2500 host/boot subset; ASPEED_AST2500A2_GP_BGA456_19x19_P0.8
U10: TPS51200DRC; VSON-10-1EP_3x3mm_P0.5mm_EP1.65x2.4mm
U11, U12: SPI NOR / capacity TBD; SOIC-8_3.9x4.9mm_P1.27mm
U20: ISL95866HRZ-T / donor reference; Renesas_L52_6x6A_QFN52_EP4.7
U21: I219-LM / revision TBD; Intel_I219_QFN48_EP3
Y1: 32.768kHz / CL TBD; Crystal_SMD_3215-2Pin_3.2x1.5mm
Y2: ABM8-25.000MHZ-D2Y-T; Crystal_SMD_3225-4Pin_3.2x2.5mm

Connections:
AUX_3V3: C204.1, U10.10
AUX_5V: R500.1, R501.1
BMC_3V3: C401.1, R402.2, R403.2, U12.8
BMC_ENTEST: R401.1, U3.K3
BMC_FLASH_HOLD#: R403.1, U12.7
BMC_FLASH_WP#: R402.1, U12.3
BMC_MIOZ: R700.1, U3.W11
BMC_MVREF: C700.1, R701.2, R702.1, U3.T9
BMC_PEREXT: R400.1, U3.K20
BMC_RX_N: C411.2, U3.M22
BMC_RX_P: C410.2, U3.M21
BMC_SPI_CLK: U3.AA18, U12.6
BMC_SPI_CS#: U3.AB19, U12.1
BMC_SPI_MISO: U3.T18, U12.2
BMC_SPI_MOSI: U3.U17, U12.5
BMC_TX_N: C413.1, U3.L22
BMC_TX_P: C412.1, U3.L21
CPU_VCCIO: R100.2, R301.2
DDR_1V2: C205.1, J1.111, J1.112, J1.117, J1.118, J1.123, J1.124, J1.129, J1.130, J1.135, J1.136, J1.141, J1.142, J1.147, J1.148, J1.153, J1.154, J1.159, J1.160, J1.163, J2.111, J2.112, J2.117, J2.118, J2.123, J2.124, J2.129, J2.130, J2.135, J2.136, J2.141, J2.142, J2.147, J2.148, J2.153, J2.154, J2.159, J2.160, J2.163, J3.111, J3.112, J3.117, J3.118, J3.123, J3.124, J3.129, J3.130, J3.135, J3.136, J3.141, J3.142, J3.147, J3.148, J3.153, J3.154, J3.159, J3.160, J3.163, J4.111, J4.112, J4.117, J4.118, J4.123, J4.124, J4.129, J4.130, J4.135, J4.136, J4.141, J4.142, J4.147, J4.148, J4.153, J4.154, J4.159, J4.160, J4.163, R203.1, U10.2
DDR_A_ACT#: J1.114, J2.114
DDR_A_ALERT#: J1.116, J2.116
DDR_A_A[0]: J1.144, J2.144
DDR_A_A[1]: J1.133, J2.133
DDR_A_A[2]: J1.132, J2.132
DDR_A_A[3]: J1.131, J2.131
DDR_A_A[4]: J1.128, J2.128
DDR_A_A[5]: J1.126, J2.126
DDR_A_A[6]: J1.127, J2.127
DDR_A_A[7]: J1.122, J2.122
DDR_A_A[8]: J1.125, J2.125
DDR_A_A[9]: J1.121, J2.121
DDR_A_A[10]: J1.146, J2.146
DDR_A_A[11]: J1.120, J2.120
DDR_A_A[12]: J1.119, J2.119
DDR_A_A[13]: J1.158, J2.158
DDR_A_A[14]: J1.151, J2.151
DDR_A_A[15]: J1.156, J2.156
DDR_A_A[16]: J1.152, J2.152
DDR_A_BA[0]: J1.150, J2.150
DDR_A_BA[1]: J1.145, J2.145
DDR_A_BG[0]: J1.115, J2.115
DDR_A_BG[1]: J1.113, J2.113
DDR_A_DQSN[0]: J1.11, J2.11
DDR_A_DQSN[1]: J1.32, J2.32
DDR_A_DQSN[2]: J1.53, J2.53
DDR_A_DQSN[3]: J1.74, J2.74
DDR_A_DQSN[4]: J1.177, J2.177
DDR_A_DQSN[5]: J1.198, J2.198
DDR_A_DQSN[6]: J1.219, J2.219
DDR_A_DQSN[7]: J1.240, J2.240
DDR_A_DQSP[0]: J1.13, J2.13
DDR_A_DQSP[1]: J1.34, J2.34
DDR_A_DQSP[2]: J1.55, J2.55
DDR_A_DQSP[3]: J1.76, J2.76
DDR_A_DQSP[4]: J1.179, J2.179
DDR_A_DQSP[5]: J1.200, J2.200
DDR_A_DQSP[6]: J1.221, J2.221
DDR_A_DQSP[7]: J1.242, J2.242
DDR_A_DQ[0]: J1.8, J2.8
DDR_A_DQ[1]: J1.7, J2.7
DDR_A_DQ[2]: J1.20, J2.20
DDR_A_DQ[3]: J1.21, J2.21
DDR_A_DQ[4]: J1.4, J2.4
DDR_A_DQ[5]: J1.3, J2.3
DDR_A_DQ[6]: J1.16, J2.16
DDR_A_DQ[7]: J1.17, J2.17
DDR_A_DQ[8]: J1.28, J2.28
DDR_A_DQ[9]: J1.29, J2.29
DDR_A_DQ[10]: J1.41, J2.41
DDR_A_DQ[11]: J1.42, J2.42
DDR_A_DQ[12]: J1.24, J2.24
DDR_A_DQ[13]: J1.25, J2.25
DDR_A_DQ[14]: J1.38, J2.38
DDR_A_DQ[15]: J1.37, J2.37
DDR_A_DQ[16]: J1.50, J2.50
DDR_A_DQ[17]: J1.49, J2.49
DDR_A_DQ[18]: J1.62, J2.62
DDR_A_DQ[19]: J1.63, J2.63
DDR_A_DQ[20]: J1.46, J2.46
DDR_A_DQ[21]: J1.45, J2.45
DDR_A_DQ[22]: J1.58, J2.58
DDR_A_DQ[23]: J1.59, J2.59
DDR_A_DQ[24]: J1.70, J2.70
DDR_A_DQ[25]: J1.71, J2.71
DDR_A_DQ[26]: J1.83, J2.83
DDR_A_DQ[27]: J1.84, J2.84
DDR_A_DQ[28]: J1.66, J2.66
DDR_A_DQ[29]: J1.67, J2.67
DDR_A_DQ[30]: J1.79, J2.79
DDR_A_DQ[31]: J1.80, J2.80
DDR_A_DQ[32]: J1.174, J2.174
DDR_A_DQ[33]: J1.173, J2.173
DDR_A_DQ[34]: J1.187, J2.187
DDR_A_DQ[35]: J1.186, J2.186
DDR_A_DQ[36]: J1.170, J2.170
DDR_A_DQ[37]: J1.169, J2.169
DDR_A_DQ[38]: J1.183, J2.183
DDR_A_DQ[39]: J1.182, J2.182
DDR_A_DQ[40]: J1.195, J2.195
DDR_A_DQ[41]: J1.194, J2.194
DDR_A_DQ[42]: J1.207, J2.207
DDR_A_DQ[43]: J1.208, J2.208
DDR_A_DQ[44]: J1.191, J2.191
DDR_A_DQ[45]: J1.190, J2.190
DDR_A_DQ[46]: J1.203, J2.203
DDR_A_DQ[47]: J1.204, J2.204
DDR_A_DQ[48]: J1.216, J2.216
DDR_A_DQ[49]: J1.215, J2.215
DDR_A_DQ[50]: J1.228, J2.228
DDR_A_DQ[51]: J1.229, J2.229
DDR_A_DQ[52]: J1.211, J2.211
DDR_A_DQ[53]: J1.212, J2.212
DDR_A_DQ[54]: J1.224, J2.224
DDR_A_DQ[55]: J1.225, J2.225
DDR_A_DQ[56]: J1.237, J2.237
DDR_A_DQ[57]: J1.236, J2.236
DDR_A_DQ[58]: J1.249, J2.249
DDR_A_DQ[59]: J1.250, J2.250
DDR_A_DQ[60]: J1.232, J2.232
DDR_A_DQ[61]: J1.233, J2.233
DDR_A_DQ[62]: J1.245, J2.245
DDR_A_DQ[63]: J1.246, J2.246
DDR_A_EVENT#: J1.134, J2.134
DDR_A_PARITY: J1.143, J2.143
DDR_B_ACT#: J3.114, J4.114
DDR_B_ALERT#: J3.116, J4.116
DDR_B_A[0]: J3.144, J4.144
DDR_B_A[1]: J3.133, J4.133
DDR_B_A[2]: J3.132, J4.132
DDR_B_A[3]: J3.131, J4.131
DDR_B_A[4]: J3.128, J4.128
DDR_B_A[5]: J3.126, J4.126
DDR_B_A[6]: J3.127, J4.127
DDR_B_A[7]: J3.122, J4.122
DDR_B_A[8]: J3.125, J4.125
DDR_B_A[9]: J3.121, J4.121
DDR_B_A[10]: J3.146, J4.146
DDR_B_A[11]: J3.120, J4.120
DDR_B_A[12]: J3.119, J4.119
DDR_B_A[13]: J3.158, J4.158
DDR_B_A[14]: J3.151, J4.151
DDR_B_A[15]: J3.156, J4.156
DDR_B_A[16]: J3.152, J4.152
DDR_B_BA[0]: J3.150, J4.150
DDR_B_BA[1]: J3.145, J4.145
DDR_B_BG[0]: J3.115, J4.115
DDR_B_BG[1]: J3.113, J4.113
DDR_B_DQSN[0]: J3.11, J4.11
DDR_B_DQSN[1]: J3.32, J4.32
DDR_B_DQSN[2]: J3.53, J4.53
DDR_B_DQSN[3]: J3.74, J4.74
DDR_B_DQSN[4]: J3.177, J4.177
DDR_B_DQSN[5]: J3.198, J4.198
DDR_B_DQSN[6]: J3.219, J4.219
DDR_B_DQSN[7]: J3.240, J4.240
DDR_B_DQSP[0]: J3.13, J4.13
DDR_B_DQSP[1]: J3.34, J4.34
DDR_B_DQSP[2]: J3.55, J4.55
DDR_B_DQSP[3]: J3.76, J4.76
DDR_B_DQSP[4]: J3.179, J4.179
DDR_B_DQSP[5]: J3.200, J4.200
DDR_B_DQSP[6]: J3.221, J4.221
DDR_B_DQSP[7]: J3.242, J4.242
DDR_B_DQ[0]: J3.8, J4.8
DDR_B_DQ[1]: J3.7, J4.7
DDR_B_DQ[2]: J3.20, J4.20
DDR_B_DQ[3]: J3.21, J4.21
DDR_B_DQ[4]: J3.4, J4.4
DDR_B_DQ[5]: J3.3, J4.3
DDR_B_DQ[6]: J3.16, J4.16
DDR_B_DQ[7]: J3.17, J4.17
DDR_B_DQ[8]: J3.28, J4.28
DDR_B_DQ[9]: J3.29, J4.29
DDR_B_DQ[10]: J3.41, J4.41
DDR_B_DQ[11]: J3.42, J4.42
DDR_B_DQ[12]: J3.24, J4.24
DDR_B_DQ[13]: J3.25, J4.25
DDR_B_DQ[14]: J3.38, J4.38
DDR_B_DQ[15]: J3.37, J4.37
DDR_B_DQ[16]: J3.50, J4.50
DDR_B_DQ[17]: J3.49, J4.49
DDR_B_DQ[18]: J3.62, J4.62
DDR_B_DQ[19]: J3.63, J4.63
DDR_B_DQ[20]: J3.46, J4.46
DDR_B_DQ[21]: J3.45, J4.45
DDR_B_DQ[22]: J3.58, J4.58
DDR_B_DQ[23]: J3.59, J4.59
DDR_B_DQ[24]: J3.70, J4.70
DDR_B_DQ[25]: J3.71, J4.71
DDR_B_DQ[26]: J3.83, J4.83
DDR_B_DQ[27]: J3.84, J4.84
DDR_B_DQ[28]: J3.66, J4.66
DDR_B_DQ[29]: J3.67, J4.67
DDR_B_DQ[30]: J3.79, J4.79
DDR_B_DQ[31]: J3.80, J4.80
DDR_B_DQ[32]: J3.174, J4.174
DDR_B_DQ[33]: J3.173, J4.173
DDR_B_DQ[34]: J3.187, J4.187
DDR_B_DQ[35]: J3.186, J4.186
DDR_B_DQ[36]: J3.170, J4.170
DDR_B_DQ[37]: J3.169, J4.169
DDR_B_DQ[38]: J3.183, J4.183
DDR_B_DQ[39]: J3.182, J4.182
DDR_B_DQ[40]: J3.195, J4.195
DDR_B_DQ[41]: J3.194, J4.194
DDR_B_DQ[42]: J3.207, J4.207
DDR_B_DQ[43]: J3.208, J4.208
DDR_B_DQ[44]: J3.191, J4.191
DDR_B_DQ[45]: J3.190, J4.190
DDR_B_DQ[46]: J3.203, J4.203
DDR_B_DQ[47]: J3.204, J4.204
DDR_B_DQ[48]: J3.216, J4.216
DDR_B_DQ[49]: J3.215, J4.215
DDR_B_DQ[50]: J3.228, J4.228
DDR_B_DQ[51]: J3.229, J4.229
DDR_B_DQ[52]: J3.211, J4.211
DDR_B_DQ[53]: J3.212, J4.212
DDR_B_DQ[54]: J3.224, J4.224
DDR_B_DQ[55]: J3.225, J4.225
DDR_B_DQ[56]: J3.237, J4.237
DDR_B_DQ[57]: J3.236, J4.236
DDR_B_DQ[58]: J3.249, J4.249
DDR_B_DQ[59]: J3.250, J4.250
DDR_B_DQ[60]: J3.232, J4.232
DDR_B_DQ[61]: J3.233, J4.233
DDR_B_DQ[62]: J3.245, J4.245
DDR_B_DQ[63]: J3.246, J4.246
DDR_B_EVENT#: J3.134, J4.134
DDR_B_PARITY: J3.143, J4.143
DDR_REFIN_0V6: C206.1, R203.2, R204.1, U10.1
DDR_RESET#: J1.108, J2.108, J3.108, J4.108
DDR_VPP_2V5: J1.257, J1.259, J2.257, J2.259, J3.257, J3.259, J4.257, J4.259
DDR_VREFCA: C203.1, J1.164, J2.164, J3.164, J4.164, U10.6
DDR_VTT: C200.1, C201.1, C202.1, J1.258, J2.258, J3.258, J4.258, U10.3, U10.5
EPS_12V: F1.1, J10.5, J10.6, J10.7, J10.8
GND: C200.2, C201.2, C202.2, C203.2, C204.2, C205.2, C206.2, C301.2, C401.2, C503.2, C504.2, C505.2, C700.2, J1.1, J1.2, J1.5, J1.6, J1.9, J1.10, J1.14, J1.15, J1.18, J1.19, J1.22, J1.23, J1.26, J1.27, J1.30, J1.31, J1.35, J1.36, J1.39, J1.40, J1.43, J1.44, J1.47, J1.48, J1.51, J1.52, J1.56, J1.57, J1.60, J1.61, J1.64, J1.65, J1.68, J1.69, J1.72, J1.73, J1.77, J1.78, J1.81, J1.82, J1.85, J1.86, J1.89, J1.90, J1.93, J1.94, J1.98, J1.99, J1.102, J1.103, J1.106, J1.107, J1.166, J1.167, J1.168, J1.171, J1.172, J1.175, J1.176, J1.180, J1.181, J1.184, J1.185, J1.188, J1.189, J1.192, J1.193, J1.196, J1.197, J1.201, J1.202, J1.205, J1.206, J1.209, J1.210, J1.213, J1.214, J1.217, J1.218, J1.222, J1.223, J1.226, J1.227, J1.230, J1.231, J1.234, J1.235, J1.238, J1.239, J1.243, J1.244, J1.247, J1.248, J1.251, J1.252, J1.256, J1.260, J2.1, J2.2, J2.5, J2.6, J2.9, J2.10, J2.14, J2.15, J2.18, J2.19, J2.22, J2.23, J2.26, J2.27, J2.30, J2.31, J2.35, J2.36, J2.39, J2.40, J2.43, J2.44, J2.47, J2.48, J2.51, J2.52, J2.56, J2.57, J2.60, J2.61, J2.64, J2.65, J2.68, J2.69, J2.72, J2.73, J2.77, J2.78, J2.81, J2.82, J2.85, J2.86, J2.89, J2.90, J2.93, J2.94, J2.98, J2.99, J2.102, J2.103, J2.106, J2.107, J2.166, J2.167, J2.168, J2.171, J2.172, J2.175, J2.176, J2.180, J2.181, J2.184, J2.185, J2.188, J2.189, J2.192, J2.193, J2.196, J2.197, J2.201, J2.202, J2.205, J2.206, J2.209, J2.210, J2.213, J2.214, J2.217, J2.218, J2.222, J2.223, J2.226, J2.227, J2.230, J2.231, J2.234, J2.235, J2.238, J2.239, J2.243, J2.244, J2.247, J2.248, J2.251, J2.252, J2.260, J3.1, J3.2, J3.5, J3.6, J3.9, J3.10, J3.14, J3.15, J3.18, J3.19, J3.22, J3.23, J3.26, J3.27, J3.30, J3.31, J3.35, J3.36, J3.39, J3.40, J3.43, J3.44, J3.47, J3.48, J3.51, J3.52, J3.56, J3.57, J3.60, J3.61, J3.64, J3.65, J3.68, J3.69, J3.72, J3.73, J3.77, J3.78, J3.81, J3.82, J3.85, J3.86, J3.89, J3.90, J3.93, J3.94, J3.98, J3.99, J3.102, J3.103, J3.106, J3.107, J3.166, J3.167, J3.168, J3.171, J3.172, J3.175, J3.176, J3.180, J3.181, J3.184, J3.185, J3.188, J3.189, J3.192, J3.193, J3.196, J3.197, J3.201, J3.202, J3.205, J3.206, J3.209, J3.210, J3.213, J3.214, J3.217, J3.218, J3.222, J3.223, J3.226, J3.227, J3.230, J3.231, J3.234, J3.235, J3.238, J3.239, J3.243, J3.244, J3.247, J3.248, J3.251, J3.252, J3.256, J4.1, J4.2, J4.5, J4.6, J4.9, J4.10, J4.14, J4.15, J4.18, J4.19, J4.22, J4.23, J4.26, J4.27, J4.30, J4.31, J4.35, J4.36, J4.39, J4.40, J4.43, J4.44, J4.47, J4.48, J4.51, J4.52, J4.56, J4.57, J4.60, J4.61, J4.64, J4.65, J4.68, J4.69, J4.72, J4.73, J4.77, J4.78, J4.81, J4.82, J4.85, J4.86, J4.89, J4.90, J4.93, J4.94, J4.98, J4.99, J4.102, J4.103, J4.106, J4.107, J4.166, J4.167, J4.168, J4.171, J4.172, J4.175, J4.176, J4.180, J4.181, J4.184, J4.185, J4.188, J4.189, J4.192, J4.193, J4.196, J4.197, J4.201, J4.202, J4.205, J4.206, J4.209, J4.210, J4.213, J4.214, J4.217, J4.218, J4.222, J4.223, J4.226, J4.227, J4.230, J4.231, J4.234, J4.235, J4.238, J4.239, J4.243, J4.244, J4.247, J4.248, J4.251, J4.252, J10.1, J10.2, J10.3, J10.4, R204.2, R400.2, R401.2, R506.2, R600.2, R601.2, R700.2, R702.2, U10.4, U10.8, U10.11, U11.4, U12.4, U20.53, U21.6, U21.49, Y2.2, Y2.4
HOST_SPI_CS#: R302.1, U11.1
HOST_VDD0P9: L600.2, U21.8, U21.11, U21.16, U21.22, U21.37, U21.40, U21.43, U21.46, U21.47
HOST_VDD3P3: U21.4, U21.15, U21.19, U21.29
HOST_XTAL_IN: U21.10, Y2.3
HOST_XTAL_OUT: U21.9, Y2.1
I219_RBIAS: R600.1, U21.12
I219_RX_N: C601.2, U21.42
I219_RX_P: C600.2, U21.41
I219_SW_0V9: L600.1, U21.7
I219_TEST_EN: R601.1, U21.30
I219_TX_N: C603.1, U21.39
I219_TX_P: C602.1, U21.38
PCH_VCCSPI: C301.1, R302.2, U11.8
PLTRST#: U3.G22, U3.L20, U21.36
SMBCLK: J1.253, J2.253, J3.253, J4.253, R201.1, U20.42
SMBDATA: J1.254, J2.254, J3.254, J4.254, R202.1, U20.43
SPD_3V3: J1.255, J2.255, J2.256, J3.255, J3.260, J4.255, J4.256, J4.260, R201.2, R202.2
VIN_12V_PROTECTED: F1.2, R502.1
VR_BOOT1_A: R520.1, U20.25
VR_BOOT1_A_CAP: C520.1, R520.2
VR_BOOT1_B: R522.1, U20.37
VR_BOOT1_B_CAP: C522.1, R522.2
VR_BOOT2_A: R521.1, U20.29
VR_BOOT2_A_CAP: C521.1, R521.2
VR_PHASE1_A: C520.2, U20.26
VR_PHASE1_B: C522.2, U20.35
VR_PHASE2_A: C521.2, U20.30
VR_PROG: R506.1, U20.10
VR_VDDP_5V: C504.1, R501.2, U20.32
VR_VDD_5V: C503.1, R500.2, U20.24
VR_VIN: C505.1, R502.2, U20.44

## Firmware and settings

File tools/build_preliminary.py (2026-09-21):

"""Generate editable, source-traceable KiCad schematic. No PCB/fabrication claims."""
import json,re,uuid,math,pathlib,collections
P=pathlib.Path; OUT=P('hardware'); OUT.mkdir(exist_ok=True)
def uid():return str(uuid.uuid4())
def q(s):return json.dumps(str(s))
def eff(size=1.0,extra=''):return f'(effects (font (size {size} {size})) {extra})'
def natural(s):return [int(t) if t.isdigit() else t for t in re.split(r'(\d+)',s)]
libs={}; instances=[]; sheetlist=[]; audit=[]; pending=[]
footprints=json.loads((OUT/'footprint-map.json').read_text())
catalog=json.loads((OUT/'parts-catalog.json').read_text())
rootid=uid(); project='x86-som-preliminary'
class Sheet:
 def __init__(self,name,title,notes):
  self.name=name;self.title=title;self.id=uid();self.sheetid=uid();self.items=[];self.used=set();sheetlist.append(self)
  self.text(title,15,15,2.5)
  self.text('PRELIMINARY v0.1 - electrically incomplete; not for fabrication',15,21,1.5)
  for i,t in enumerate(notes):self.text(t,15,29+i*5,1.15)
 def text(self,s,x,y,size=1.0):self.items.append(f'(text {q(s)} (at {x} {y} 0) {eff(size,"(justify left)")} (uuid {q(uid())}))')
 def wire(self,x1,y1,x2,y2):self.items.append(f'(wire (pts (xy {x1} {y1}) (xy {x2} {y2})) (stroke (width 0) (type default)) (uuid {q(uid())}))')
 def label(self,s,x,y,angle=0):self.items.append(f'(global_label {q(s)} (shape bidirectional) (at {x} {y} {angle}) {eff(.9,"(justify left)" if angle==0 else "(justify right)")} (uuid {q(uid())}))')
 def nc(self,x,y):self.items.append(f'(no_connect (at {x} {y}) (uuid {q(uid())}))')
 def symbol(self,lib,ref,x,y,nets,unit=1,value=None):
  x=round(x/1.27)*1.27;y=round(y/1.27)*1.27
  spec=libs[lib];u=spec['units'][unit-1];self.used.add(lib);iid=uid()
  val=value or spec['value'];h=u['height']
  props=f'(property "Reference" {q(ref)} (at {x} {y-5} 0) {eff(1.4)}) (property "Value" {q(val)} (at {x} {y-2} 0) {eff(1.2)})'
  props+=f'(property "Footprint" {q(footprints.get(lib,""))} (at {x} {y} 0) {eff(1,"hide")})'
  for key in ['Manufacturer','MPN','Datasheet','Status']:
   props+=f'(property {q(key)} {q(catalog.get(lib,{}).get(key,""))} (at {x} {y} 0) {eff(1,"hide")})'
  path=f'/{rootid}/{self.sheetid}'
  self.items.append(f'(symbol (lib_id {q("SOM:"+lib)}) (at {x} {y} 0) (unit {unit}) (in_bom yes) (on_board yes) (dnp no) (uuid {q(iid)}) {props} (instances (project {q(project)} (path {q(path)} (reference {q(ref)}) (unit {unit})))))')
  seen=set()
  for p in u['pins']:
   px=x+p['x'];py=y-p['y'];net=nets.get(p['pin']);audit.append(dict(ref=ref,pin=p['pin'],name=p['name'],net=net,sheet=self.name,source=spec['source']))
   loc=(px,py)
   if loc in seen:continue
   seen.add(loc)
   if net=='NC':self.nc(px,py)
   elif net:
    end=px+(-10.16 if p['x']<0 else 10.16);self.wire(px,py,end,py);self.label(net,end,py,0 if p['x']<0 else 180)
   else:pending.append(dict(ref=ref,pin=p['pin'],name=p['name'],sheet=self.name))
 def part(self,kind,ref,value,x,y,a,b,source='Provisional value; see sheet notes'):
  self.symbol(kind,ref,x,y,{'1':a,'2':b},value=value)
 def save(self):
  definitions='\n'.join(libs[k]['sexp'].replace('(symbol '+q(k),'(symbol '+q('SOM:'+k),1) for k in sorted(self.used))
  s=f'(kicad_sch (version 20250114) (generator "eeschema") (uuid {q(self.id)}) (paper "A2") (title_block (title {q(self.title)}) (rev "0.1-PRELIMINARY") (comment 1 "NOT FOR FABRICATION - see open-items.md")) (lib_symbols {definitions}) '+ '\n'.join(self.items)+')'
  (OUT/(self.name+'.kicad_sch')).write_text(s)
def define(name,units,source,value=None,width=66.04):
 allpins=[];us=[];sx=[f'(symbol {q(name)} (pin_names (offset 1.016)) (in_bom yes) (on_board yes) (property "Reference" "U" (at 0 5 0) {eff()}) (property "Value" {q(value or name)} (at 0 2 0) {eff()}) (property "Datasheet" {q(source)} (at 0 0 0) {eff(1,"hide")} )']
 for n,pins in enumerate(units,1):
  # Stack supply pins only when explicitly requested by same group.
  groups=[];by={}
  for p in pins:
   p=dict(p);key=p.get('stack',p['pin'])
   if key not in by:by[key]=len(groups);groups.append([])
   groups[by[key]].append(p)
  half=math.ceil(len(groups)/2);height=max(10.16,(half+1)*3.81);placed=[]
  body=f'(symbol {q(name+"_"+str(n)+"_1")} (rectangle (start {-width/2} 0) (end {width/2} {-height}) (stroke (width .254) (type default)) (fill (type background)))'
  # append pins within the unit definition
  # unit remains open after rectangle
  for k,group in enumerate(groups):
   side=-1 if k<half else 1;row=k if k<half else k-half;xx=side*(width/2+5.08);yy=-(row+1)*3.81
   for j,p in enumerate(group):
    p.update(x=xx,y=yy);placed.append(p);label=p['name'] if j==0 else p['name'];hide='hide' if j else ''
    typ=p.get('type','passive') if j==0 else 'passive';label=(p.get('stack')+' ['+str(len(group))+']') if len(group)>1 and j==0 else label
    body+=f'(pin {typ} line (at {xx} {yy} {0 if side<0 else 180}) (length 5.08) {hide} (name {q(label)} {eff(.95)}) (number {q(p["pin"])} {eff(.85)}))'
  body+=')';sx.append(body);us.append(dict(pins=placed,height=height));allpins+=placed
 sx.append(')');libs[name]=dict(sexp='\n'.join(sx),units=us,source=source,value=value or name)
 assert len({p['pin'] for p in allpins})==len(allpins),(name,'duplicate pins')
def pin(n,name,typ='passive',**kw):return dict(pin=str(n),name=name,type=typ,**kw)
# Standard two-terminal components, kept native/editable.
for kind in ['R','C','L','FUSE','XTAL']:
 define(kind,[[pin(1,'1'),pin(2,'2')]],'Conventional two-terminal symbol',width=10.16)
 # Replace the generic body by a conventional outline for R/C.
 if kind in ['R','C']:
  geom='(polyline (pts (xy -2.54 -3.81) (xy -5.08 -3.81)) (stroke (width 0) (type default)) (fill (type none))) (polyline (pts (xy 2.54 -3.81) (xy 5.08 -3.81)) (stroke (width 0) (type default)) (fill (type none)))'
  if kind=='R':geom+='(rectangle (start -2.54 -5.08) (end 2.54 -2.54) (stroke (width .254) (type default)) (fill (type none)))'
  else:geom+=''.join(f'(polyline (pts (xy {x} -6.35) (xy {x} -1.27)) (stroke (width .254) (type default)) (fill (type none)))' for x in [-.635,.635])+ '(polyline (pts (xy -2.54 -3.81) (xy -.635 -3.81)) (stroke (width 0) (type default)) (fill (type none))) (polyline (pts (xy .635 -3.81) (xy 2.54 -3.81)) (stroke (width 0) (type default)) (fill (type none)))'
  libs[kind]['sexp']=re.sub(r'\(rectangle \(start .*?\(fill \(type background\)\)\)',geom,libs[kind]['sexp'],count=1)
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

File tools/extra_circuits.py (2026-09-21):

# Additional source-transcribed draft circuits. Executed by build_preliminary.py.
vr=json.loads(P('research/vrm-pin-extraction.json').read_text())
vr +=[pin(24,'VDD','power_in'),pin(32,'VDDP','power_in'),pin(53,'GND_EP','power_in')]
define('ISL95866_reference',[vr],'H310M-S2P 2.0 sheet25; populated options differ for ISL95856/ISL95866',value='ISL95866HRZ-T / donor reference')
s=Sheet('15_vrm_controller','CPU VR controller / source-based starting circuit',['Transcribed pinout and bias/bootstrap networks: H310M-S2P 2.0 sheet25. This does not constitute a complete VRM.','Donor contains ISL95856/ISL95866 population alternatives. Phase mapping, compensation and current sense remain open.'])
vnets={p['pin']:'VR_'+p['name']for p in vr}
vnets.update({'24':'VR_VDD_5V','32':'VR_VDDP_5V','53':'GND','44':'VR_VIN','5':'CPU_SVID_CLK','6':'CPU_SVID_ALERT#','7':'CPU_SVID_DATA','8':'CPU_VR_ENABLE','11':'CPU_VR_READY','4':'CPU_VR_HOT#','43':'SMBDATA','42':'SMBCLK','20':'CPU_VSS_SENSE','48':'CPU_VSSGT_SENSE'})
s.symbol('ISL95866_reference','U20',130,60,vnets)
for i,(a,b,val,kind) in enumerate([('AUX_5V','VR_VDD_5V','2.2R','R'),('AUX_5V','VR_VDDP_5V','2.2R','R'),('VIN_12V_PROTECTED','VR_VIN','2.2R','R'),('VR_VDD_5V','GND','1uF','C'),('VR_VDDP_5V','GND','1uF','C'),('VR_VIN','GND','1uF','C'),('VR_PROG','GND','2.87k 1% / donor','R')]):
 s.part(kind,f'{kind}{500+i}',val,330,65+i*28,a,b)
for i,phase in enumerate(['1_A','2_A','1_B']):
 s.part('R',f'R{520+i}','2.2R / donor',470,65+i*65,f'VR_BOOT{phase}',f'VR_BOOT{phase}_CAP')
 s.part('C',f'C{520+i}','220nF / donor',470,95+i*65,f'VR_BOOT{phase}_CAP',f'VR_PHASE{phase}')
s.text('UGATE/LGATE/PHASE are unconnected power-stage interfaces. Feedback/current-sense must be completed before power-on.',20,330,1.25)
s.text('CPU_VCORE and CPU_VCCGT are not generated in this draft. Donor sheets26-27 retain exact MOSFET/driver circuits.',20,340,1.25)
s.text('CPU SVID source pull-up/series networks and PSYS/IMON/NTC programming remain required.',20,350,1.25)
# I219: all package contacts plus exposed pad; external generation compatibility still open.
ih={1:'RSVD1_VCC3P3',2:'LANWAKE_N',3:'LAN_DISABLE_N',4:'VDD3P3',5:'VDD3P3_IN',6:'SVR_EN_N',7:'CTRL0P9',9:'XTAL_OUT',10:'XTAL_IN',12:'RBIAS',13:'MDI_PLUS0',14:'MDI_MINUS0',17:'MDI_PLUS1',18:'MDI_MINUS1',20:'MDI_PLUS2',21:'MDI_MINUS2',23:'MDI_PLUS3',24:'MDI_MINUS3',25:'LED2',26:'LED0',27:'LED1',28:'SMB_CLK',30:'TEST_EN',31:'SMB_DATA',32:'JTAG_TDI',33:'JTAG_TMS',34:'JTAG_TDO',35:'JTAG_TCK',36:'PE_RST_N',38:'PETp',39:'PETn',41:'PERp',42:'PERn',44:'PE_CLKP',45:'PE_CLKN',48:'CLK_REQ_N',49:'GND_EP'}
for k in [8,11,16,22,37,40,43,46,47]:ih[k]='VDD0P9'
for k in [15,19,29]:ih[k]='VDD3P3'
ip=[pin(k,v,stack=v) if v.startswith('VDD')else pin(k,v)for k,v in sorted(ih.items())]
define('I219_reference',[ip],'Intel I219 datasheet sections3.1.2-3.1.7 pp36-38; exposed ground pad',value='I219-LM / revision TBD')
s=Sheet('16_host_lan','Host GbE PHY / I219 reference circuit',['Intel I219 full datasheet pin tables. Exact I219-LM generation and Q370 compatibility must be selected before BOM freeze.','Uses PCH GbE on HSIO10 / PCIe lane5. This link consumes the shared lane; it is not an additional expansion root port.'])
nets={str(k):'HOST_'+v for k,v in ih.items()}
nets.update({'49':'GND','5':'LAN_AUX_3V3','6':'GND','7':'I219_SW_0V9','12':'I219_RBIAS','30':'I219_TEST_EN','36':'PLTRST#','38':'I219_TX_P','39':'I219_TX_N','41':'I219_RX_P','42':'I219_RX_N','44':'I219_REFCLK_P','45':'I219_REFCLK_N','28':'I219_SML_CLK','31':'I219_SML_DATA'})
s.symbol('I219_reference','U21',135,60,nets)
s.part('L','L600','4.7uH / Intel',365,70,'I219_SW_0V9','HOST_VDD0P9')
s.part('R','R600','3.01k 1%',365,100,'I219_RBIAS','GND');s.part('R','R601','1k',365,130,'I219_TEST_EN','GND')
define('ABM8',[[pin(1,'XTAL1'),pin(2,'GND'),pin(3,'XTAL2'),pin(4,'GND')]],'Abracon ABM8 datasheet',value='ABM8-25.000MHZ-D2Y-T',width=10.16)
s.symbol('ABM8','Y2',365,160,{'1':'HOST_XTAL_OUT','2':'GND','3':'HOST_XTAL_IN','4':'GND'})
for i,(a,b)in enumerate([('HOST_LAN_TX_P','I219_RX_P'),('HOST_LAN_TX_N','I219_RX_N'),('I219_TX_P','HOST_LAN_RX_P'),('I219_TX_N','HOST_LAN_RX_N')]):s.part('C',f'C{600+i}','100nF / provisional',130+(i//2)*235,225+(i%2)*30,a,b)
s.text('Open: LANPHYPC / LAN_DISABLE logic, SMLink wiring, source clock+CLKREQ, internal regulator caps and strap pull-ups.',20,320,1.25)
s.text('MDI pairs go to carrier magnetics/RJ45; no magnetics or termination network is included yet.',20,330,1.25)
# BMC DDR signal inventory from datasheet. Real package balls; no fictitious DRAM pinout.
a=P('docs/text/ast2500.txt').read_text().split('\f');ap=[]
for pg in [51,52]:
 for line in a[pg-1].splitlines():
  m=re.match(r'^\s*([A-Z]{1,2}[0-9]{1,2})\s+(M[A-Z0-9_/#]+)(?:\s|$)',line)
  if m:ap.append(pin(m[1],m[2]))
define('AST2500_ddr_draft',[ap],'AST2500 A2 v1.6 pp51-52; DDR3L/DDR4 multiplexing',value='AST2500 DDR / interface subset')
# Separate reference designator avoids pretending this is a second BMC part in the BOM:
# Merge into the existing BMC symbol as second unit, so U3 remains one physical device.
old=libs['AST2500_host_draft'];define('AST2500_host_draft',[astpins,ap],old['source']+'; DDR pp51-52',value=old['value'])
s=Sheet('17_bmc_ddr','AST2500 local DDR4 / pin-level interface',['AST2500 DDR4 x16 interface from full datasheet pp51-52. Exact DRAM part and footprint remain unselected.','MA14/MACT#, MBA aliases and required memory geometry must be reconciled with chosen DDR4 before connecting its balls.'])
ns={p['pin']:'BMC_'+p['name']for p in ap}
s.symbol('AST2500_host_draft','U3',130,60,ns,2)
s.part('R','R700','240R 1%',365,80,'BMC_MIOZ','GND')
s.part('R','R701','10k 0.1% / provisional',365,125,'BMC_DDR_1V2','BMC_MVREF');s.part('R','R702','10k 0.1% / provisional',365,155,'BMC_MVREF','GND');s.part('C','C700','100nF',365,185,'BMC_MVREF','GND')
s.text('This sheet is an unfinished memory circuit: 53 BMC interface pins are available, but no RAM component is represented.',20,320,1.25)
s.text('BMC core/power domains, RGMII management PHY, reset supervisor and complete strap matrix remain required.',20,330,1.25)
